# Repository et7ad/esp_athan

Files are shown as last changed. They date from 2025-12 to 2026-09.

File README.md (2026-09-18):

# Athan Clock (ESPHome on an ESP8266)

A small clock that calls the Athan at the exact times of your local mosque. It shows the time and the next prayer on a little screen, plays the Athan through a speaker, and takes its prayer times from tiny JSON files that live in this repository (or any other repository in case you want to replicate the project on your own), one file per day per mosque. This project was built because I could not find one that follows my own mosque's timetable and keeps working when I move.

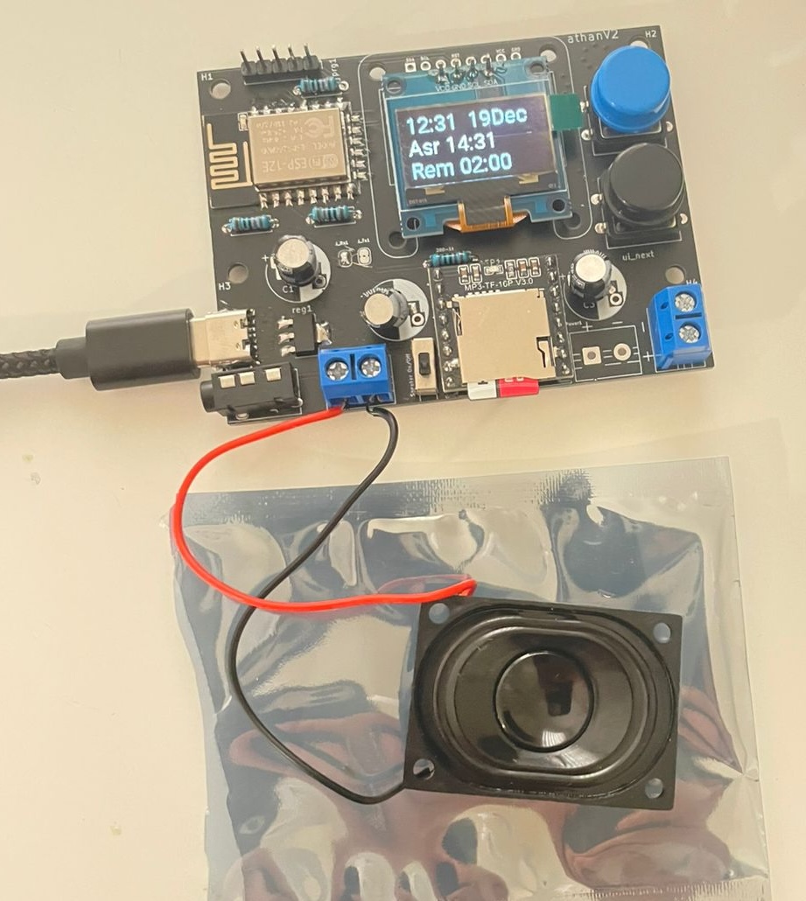
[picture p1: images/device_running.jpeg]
Device running


**Who should read what**

| You are... | Read | Why |
|---|---|---|
| **Someone who already has a device** | **Section 1 only.** | Everything you need to set it up should be in this section. |
| Someone who wants to build one | Section 2 | Parts, wiring, PCB, 3D printed case, preparing the memory card. Needs soldering and a bit of patience. |
| Someone who wants to add a mosque's timetable, or host the data yourself | Section 3 | How the prayer times are stored and served. |
| Someone who wants to change how the firmware behaves | Section 4 and `DEVELOPER.md` | The code is one ESPHome file; the internals are documented there. |

---

## 1. You have the device in your hands

Setting it up is two steps. One, you connect it to your home Wi‑Fi. After that, everything is set from a web page that the clock itself shows on your phone or computer. You can alternatively use the two buttons on the front to do the same things (I think the web page is faster though).

### 1.1 First power‑up: connect it to your Wi‑Fi (once)

1. Plug it in and wait > **2 to 3 minutes**.
2. On your laptop (or phone), open the Wi‑Fi list. A network called **`AthanFallbackHotspot`** appears. Join it with the password **`athan404`**.
3. A page opens by itself asking for your home Wi‑Fi. If it does not, open a browser and go to `192.168.4.1`.
4. Pick your home Wi‑Fi (or enter its SSID manually), type its password, save.
5. The clock restarts, joins your Wi‑Fi, sets its own time from the internet, downloads today's prayer times, and shows the time and the next prayer. From then on it does this by itself every day.

You do this **once**. The clock keeps the Wi‑Fi you gave it, together with all your other settings, in its own memory: unplug it, move it to another socket, leave it off for a month, plug it back in, and it reconnects to the same network by itself. The hotspot only comes back when you want a different network (see below) or when the network it knows is not there.

Two things to know:

- The clock only sees **2.4 GHz** Wi‑Fi networks. Most home routers have one; if yours shows two networks (for example "home" and "home‑5G"), pick the one without "5G".
- If you move it to another home, just plug it in: when it cannot find the Wi‑Fi it knows, it opens the `AthanFallbackHotspot` network by itself after two or three minutes, and you repeat steps 2 to 4. However, if you want to make it **forget** a Wi‑Fi when that network is still in range (for example to move the clock to a different network in the same home): plug it in **while holding both front buttons**, then let go. Within a little while the LED blinks twice, the clock restarts, and the hotspot appears.

### 1.2 Set everything from the web page

On a phone or computer connected to the same Wi‑Fi, open a browser and go to:

**`http://athan.local`**

If that address does not open (it depends on your phone and router, and Android phones usually cannot open `.local` names), use the clock's own IP address instead: on the device use the two buttons, press **Select** (the upper button), then press **Next** (the lower button) until the screen says **Info**, press **Select** again, and the screen shows an address like `192.168.1.42`. Type that into the browser. Your router's app or admin page also lists it, under the name `athan`. (optional): You usually can tell your router to always give the clock the same address (this is often called "DHCP reservation" or "static lease") and bookmark it.

<table><tr>
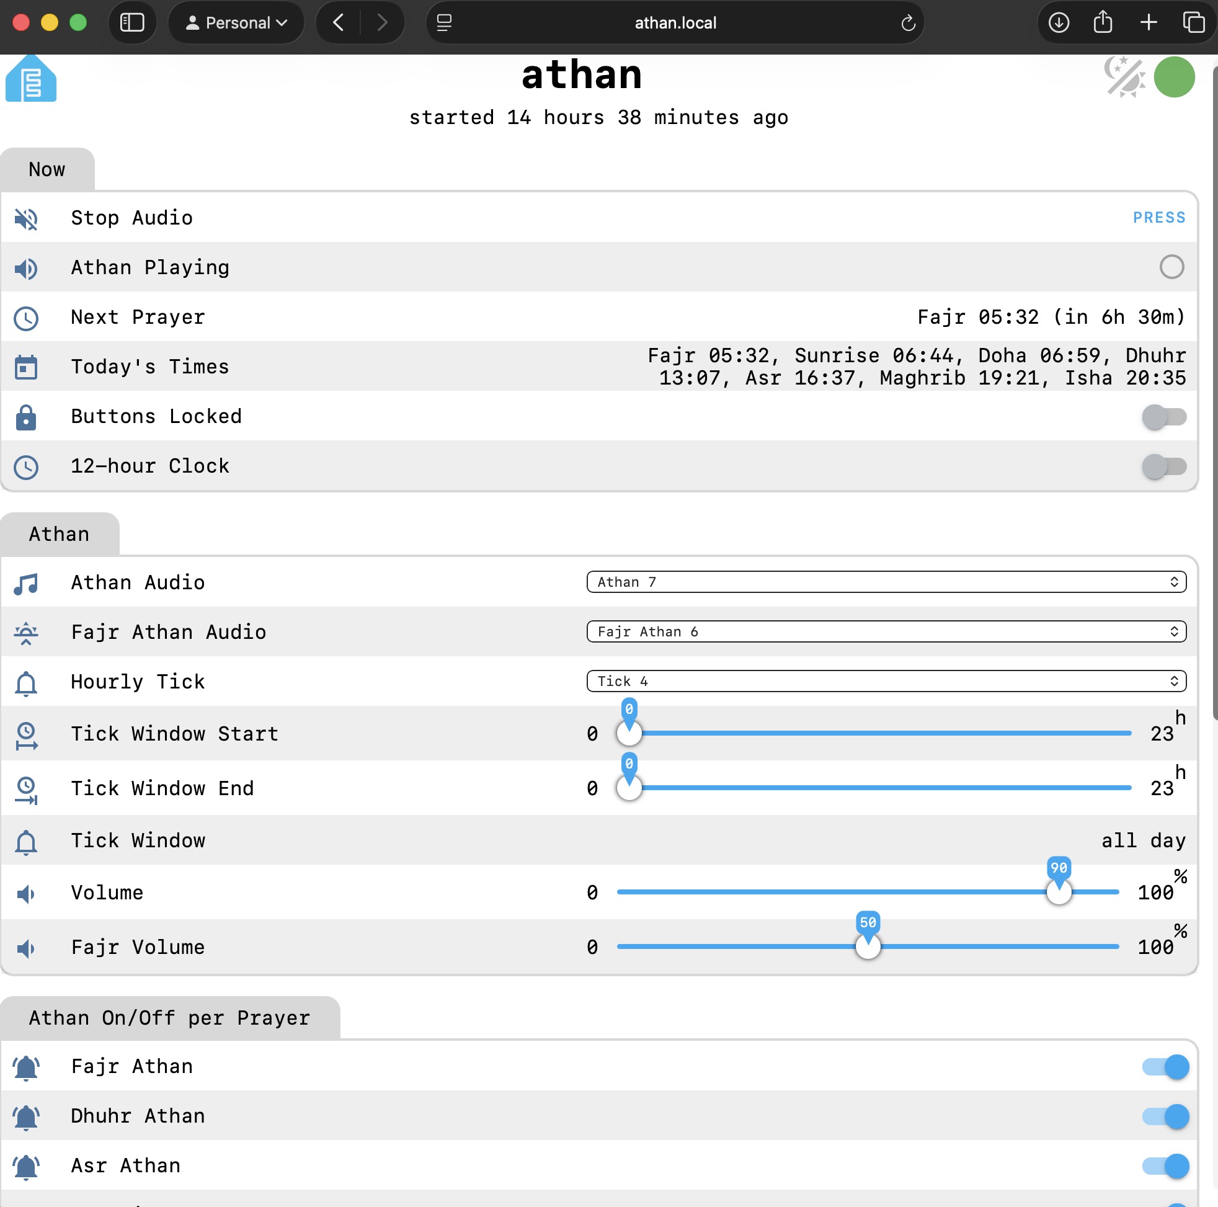
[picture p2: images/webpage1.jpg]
Web page, top half
<td></td>
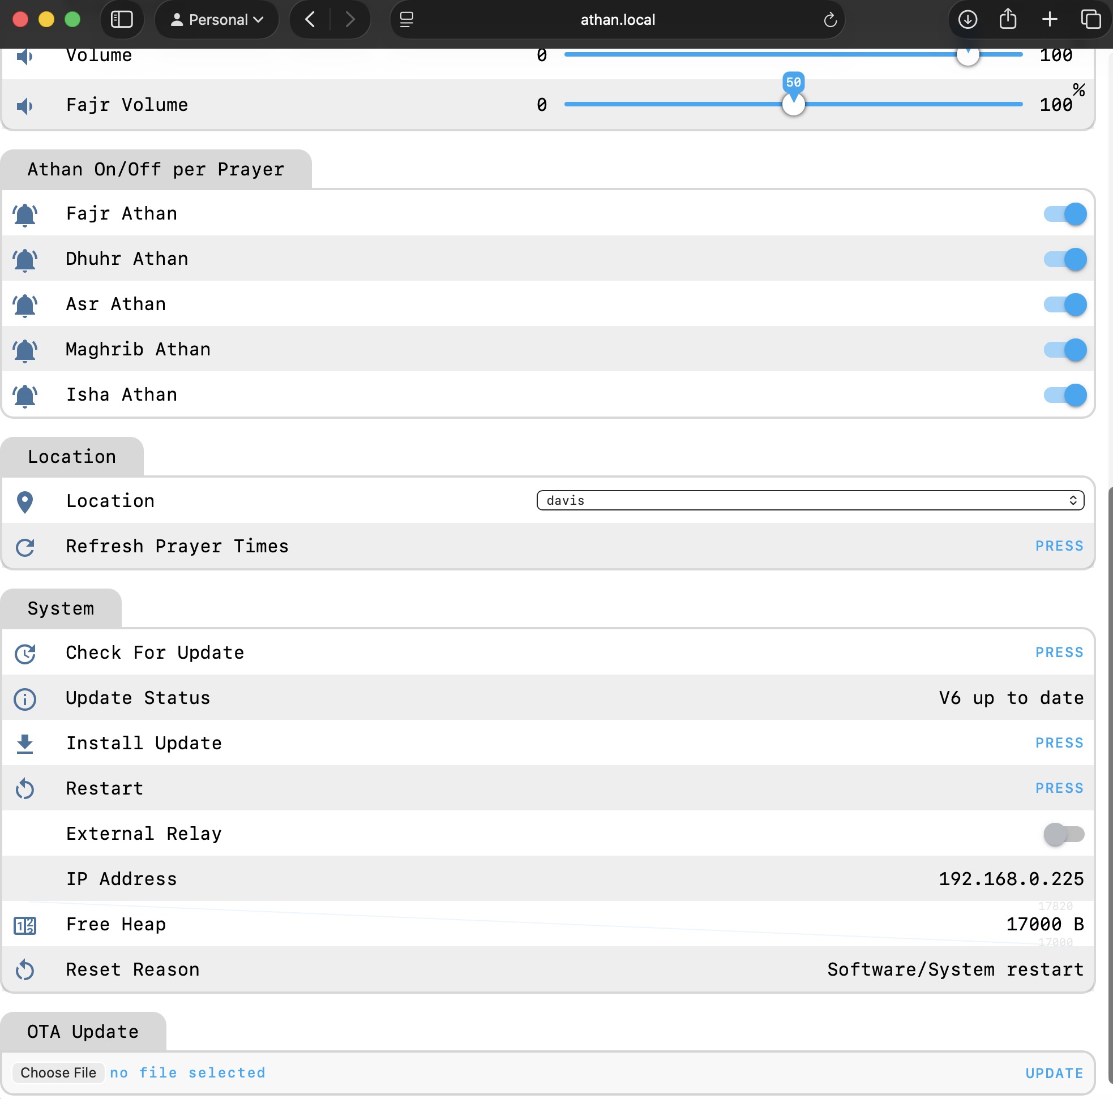
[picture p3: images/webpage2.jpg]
Web page, bottom half
<td></td>
</tr></table>

The page is organised in groups:

- **Location** – your mosque. Pick it from the list and the clock downloads that mosque's timetable and time zone. The list of mosques is in section 3.4; if yours is missing, ask me and I will add it.
- **Athan Audio** – which athan-recording is used for Dhuhr, Asr, Maghrib and Isha. Changing it plays a 20‑second preview.
- **Fajr Athan Audio** – which athan-recording is used for Fajr. Also previews.
- **Volume** and **Fajr Volume** – the Fajr Athan has its own volume, so it can be gentler at dawn (or more loud if you want to count on it to wake you up 😴).
- **Hourly Tick** – an optional short sound at the top of every hour, and **Tick Window Start / End** to allow it only during part of the day. The tick plays at every full hour from Start up to, but not including, End: with Start 7 and End 22 it ticks at 7:00, 8:00 … 21:00 and stays quiet at night. The window can be any stretch of the day, including one that runs through midnight: set Start *higher* than End (for example Start 22, End 7) and it ticks from 22:00 through the night until 6:00. On the page that simply means the upper slider sits higher than the lower one. Start equal to End means all day. You can completely turn the tick off by choosing **None** for the sound.
- **Fajr / Dhuhr / Asr / Maghrib / Isha Athan** – five switches to turn the call off for a particular prayer. The clock still shows and counts down to that prayer; it just stays silent. Visual cue: if the Athan is off, the next prayer name on the screen is partially str~~icken~~-thr~~oug~~
- **12‑hour Clock** – show `5:04 PM` instead of `17:04`.
- **Buttons Locked** – makes the two front buttons do nothing except silence the sound (I guess mainly for kids?). See 1.3 for how to unlock without the page.
- **Stop Audio** – silences whatever is playing right now.
- **Next Prayer**, **Today's Times**, **Athan Playing** – just information.
- **Check For Update / Install Update** – firmware updates, see 1.4.
- **Restart**, **External Relay**, **IP Address**, **Free Heap**, **Reset Reason** – restart the clock; switch the relay output if you connected something to it; the address to type in your browser; and two numbers for degbugging purposes that I may ask you for if something goes wrong.

Anything you change on the page takes effect immediately, and the page always shows what the clock is currently doing, even if it was changed with the buttons.

### 1.3 The screen and the two buttons

The screen normally shows three lines: the time and date, the next prayer and its time, and how long until it. A small padlock in the bottom‑right corner means the buttons are locked. A crossed circle with a **W** means the clock has lost Wi‑Fi (it keeps working; it just cannot download tomorrow's times until Wi‑Fi is back).

The two buttons:

- **Select** (upper) – opens the menu. Inside the menu it confirms. While the Athan is playing it silences it.
- **Next** (lower) – inside the menu it moves to the next item. On the normal screen it silences the Athan if one is playing; otherwise it toggles the relay output.

The menu closes by itself after a minute without presses. Its items, in order:

| Item | What it does |
|---|---|
| Athan | choose the recording for Dhuhr, Asr, Maghrib, Isha (Next previews, Select keeps) |
| Fajr Athan | choose the recording for Fajr (previews at the Fajr volume) |
| Athan On/Off | Next moves through Fajr, Dhuhr, Asr, Maghrib, Isha; Select flips one on or off; Select on **Done** leaves |
| Hourly Tick | choose the hourly sound, or None |
| Tick Window | Next moves between Start, End and Done; Select on Start or End lets Next change the hour; Select again confirms. The third line always shows how long the window is. Start above End means the window runs through midnight |
| Location | your mosque |
| Update | first Select checks for a new firmware, second Select installs it |
| Volume | Next lowers by 10 % (wraps around to 100 %), a tone plays at the new level, Select keeps |
| Fajr Volume | the same, for Fajr |
| Clock | Select flips between 24h and 12h |
| Lock Buttons | Select locks the buttons and returns to the clock |
| Info | firmware version, the clock's IP address and its `athan.local` name |
| Cancel | back to the clock |
| Q | an advanced option that is **off** by default. If it is ever **ON** press select to turns it off |

To **unlock** the buttons without the web page: unplug the clock, then plug it back in while holding **one** of the two buttons (either one). The LED blinks three times quickly and the buttons work again.

### 1.4 Living with it

- **At prayer time** the Athan plays and the LED stays on for a few minutes. Either button, or **Stop Audio** on the page, silences it. Sunrise and Doha are shown but never call.
- **Fajr** uses its own recording and its own volume, the ones you chose under Fajr Athan Audio and Fajr Volume.
- **Firmware updates** need no cable. On the page press **Check For Update**; if a newer version exists, **Install Update**. On the device: menu, **Update**, Select twice. The clock restarts by itself when done.
- **No screen?** The clock works without it: it still calls the Athan and serves the web page. If you plug a screen in later it comes alive within about 10 seconds.
- **Speaker too quiet?** The board has a jack for an external powered speaker (any small PC speaker with its own power). Plug it in and flip the small speaker switch on the board so only the external one is used.

### 1.5 If something is off

- **`athan.local` does not open.** Use the IP address instead (section 1.2). Android in particular never opens `.local` names. Some routers also answer `http://athan/` or `http://athan.lan/`.
- **The buttons do nothing.** Look for the padlock in the corner: the buttons are locked. Switch **Buttons Locked** off on the page, or unplug and replug while holding one button.
- **The sound is wrong: nothing plays, several clips play one after another, the wrong recording, or it keeps playing on its own.** The audio module inside is probably a clone of a common MP3 player and occasionally gets confused, most often right after a button press. The firmware already avoids the usual triggers, but when it happens the fix is simple: **unplug the power and plug it back in.** That is all it needs.
- **The screen is dark or frozen.** Screens clones occasionally lock up; unplug and replug fixes them too. If you unplugged the screen yourself while the clock was running, plugging it back in is handled once; a second time needs a power cycle. The clock keeps calling the Athan meanwhile.
- **The time or the prayer times look wrong.** Check the Wi‑Fi mark on the screen and the **Location** on the page, then press **Refresh Prayer Times**. The clock can only download times when it is online; if it has been offline for more than a day it keeps yesterday's times until it reconnects.
- **You want to see the last restart reason or the memory.** They are the last two rows on the page. If **Reset Reason** ever says `Exception`, tell me; it is not expected.

### 1.6 Home Assistant (optional)

If you run Home Assistant, add the clock through the ESPHome integration; it is discovered automatically. When asked for the key, use:

`jAOYf5QQGoONCqGQnC7fwPhSeb/ZTUTlawp1Lvu63ZI=`

Everything on the web page becomes an entity in Home Assistant: the selects, sliders, switches, buttons and readouts. The **External Relay** switch is handy for things like the IoT power strip below, to switch an amplifier or a light with the Athan.

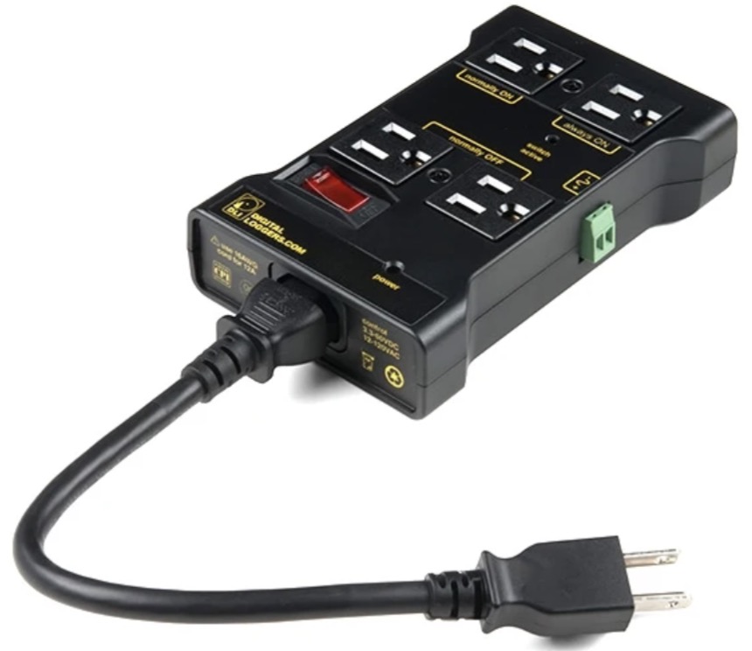
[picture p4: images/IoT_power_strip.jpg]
IoT Power Strip


That is the end of what a device owner needs. The rest of this page is for people building, feeding or changing the clock.

---

## 2. Building your own device

For people who are comfortable with basic electronics and 3D printing and want to assemble a unit from scratch. You will end up with the same device described in section 1.

### 2.1 Parts

- ESP8266 D1 Mini (or an ESP‑12 module, as on the PCB).
- DFPlayer Mini MP3 module with a microSD card.
- SSD1306 128×64 I2C OLED display.
- Two momentary push buttons (Next, Select).
- Optional relay module on `GPIO13`.
- 5 V input, 3.3 V regulator for the ESP8266, a speaker or an external powered speaker on the jack.

The parts list with pictures is in `BOM.md`, which points at the KiCad‑generated BOM files under `hardware/pcb/athan_kicad/BOM/`.

### 2.2 Wiring

`WIRING.md` has the full pin table and decoupling notes. In short:

- OLED on I2C: `GPIO4` (SDA), `GPIO5` (SCL); reset on `GPIO16` (only 7/8‑pin modules have it).
- DFPlayer on the hardware UART: `GPIO1` (TX) and `GPIO3` (RX), powered from 5 V.
- Built‑in LED on `GPIO2`.
- Next on `GPIO14`, Select on `GPIO12`, both with the ESP's internal pull‑ups.
- Relay on `GPIO13`.

A breadboard build works with the same pins.

### 2.3 PCB and enclosure files

- KiCad project (schematic, layout, settings): `hardware/pcb/athan_kicad/`. Renders: `hardware/pcb/athan_kicad/generated_imgs_and_3d/`.
- Enclosure (STL, STEP, Fusion, and a ready gcode): `hardware/encolsure/Iteration13/`. There are top halves for a round or a rectangular speaker and for two display variants; pick the pair that matches your parts.

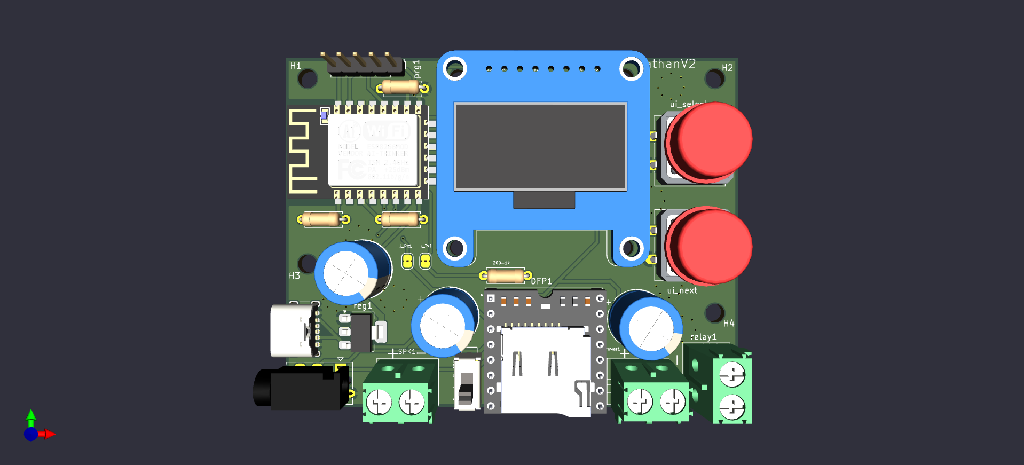
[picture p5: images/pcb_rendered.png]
PCB rendered

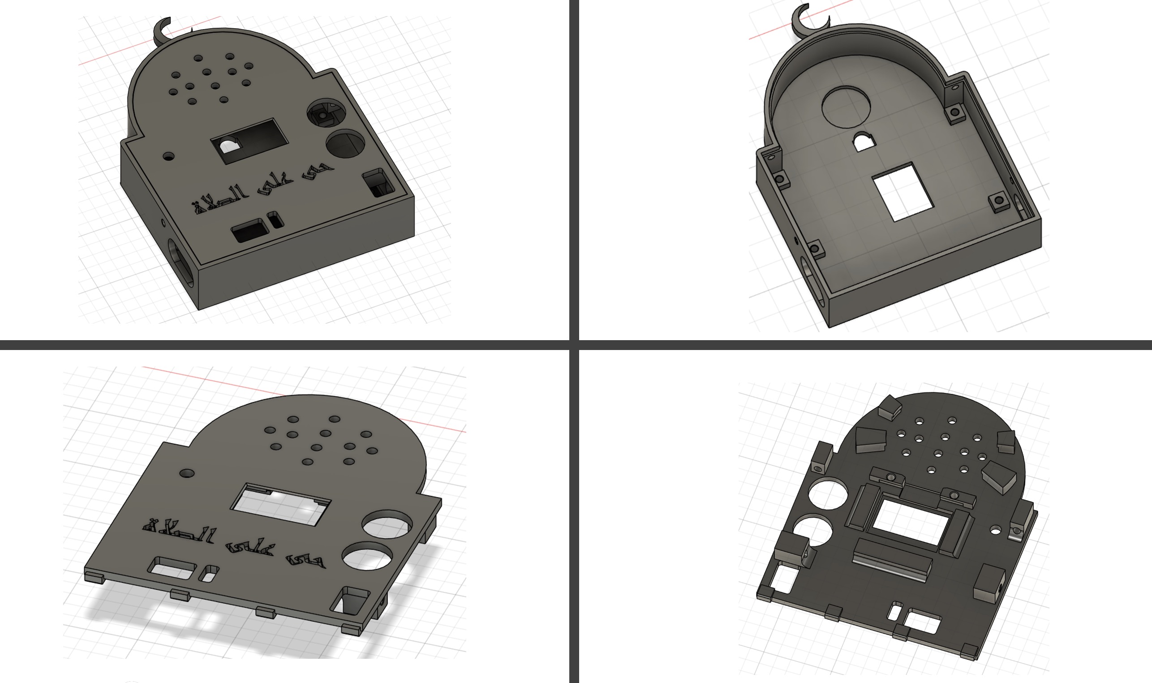
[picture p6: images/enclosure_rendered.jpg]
Enclosure rendered


The PCB accepts several OLED footprints: an 8‑pin header, two 4‑pin I2C footprints with the two common pin orders (`GND‑VCC‑SCL‑SDA` and `VCC‑GND‑SCL‑SDA`; match your module's silkscreen), and a 7‑pin SPI footprint that the firmware does not use.

### 2.4 Flashing the first time

The DFPlayer shares the UART pins that are also used for programming, so the order matters:

1. Solder the ESP module, the power parts and the headers. **Do not solder the DFPlayer yet.**
2. Connect a 3.3 V USB‑to‑serial adapter (CP2102, CH340, FT232...) to the programming pins: `GND` to `GND`, adapter TX to `ESP_RX`, adapter RX to `ESP_TX`, 3.3 V to `ESP_VCC`. Never feed 5 V into `ESP_VCC`.
3. Hold `GPIO0` to `GND` while powering up; that puts the ESP8266 into its serial bootloader.
4. Flash the firmware. Either build it yourself from `firmware/athan.yaml` with ESPHome (you need a `secrets.yaml` next to it with `wifi_ssid` and `wifi_password`), or flash a released `.bin` with `web.esphome.io` in a supported browser, or any ESP8266 flashing tool.
5. Now solder the DFPlayer.

From the second PCB revision on, the DFPlayer's UART lines pass through a small solder jumper, bridged by default. If you ever need the serial header again with the DFPlayer already in place, cut the jumper, flash, and bridge it again with a blob of solder.

### 2.5 Flashing afterwards (no cable)

- From the device: menu, **Update** (checks `docs/firmwareinfo/latest.json` in this repo, then installs).
- From the web page: **Check For Update** and **Install Update**, or the **OTA Update** form at the bottom of the page where you pick a `.bin` file. In Safari on macOS the file picker greys out `.bin` files; use Chrome, or from a terminal:

  ```bash
  curl -F "update=@/path/to/firmware.bin" http://athan.local/update
  ```

- From the ESPHome dashboard or CLI (`esphome run firmware/athan.yaml`).
- If the clock is in its `AthanFallbackHotspot` mode, `http://192.168.4.1` also offers a firmware upload.

If you host your own firmware for the in‑device update, the `.md5` file next to the `.bin` must contain only the checksum string, nothing else.

### 2.6 Preparing the memory card

The DFPlayer does not care about file names; it numbers files by the **order they were copied** to the card. So the card better be written by the script, not by drag and drop.

1. Put the card in the computer (Mac or Linux). Everything on it will be erased, whatever its name or content.
2. Put the audio files in one folder on your computer, named as in the table below.
3. Open `scripts/sd_card_cpy_script.sh` and set `SRC` to that folder. On a Mac also set `DEST` to the mounted card (for example `/Volumes/AUDIO`); on Linux leave `DEST` alone.
4. Run it in a terminal: `bash scripts/sd_card_cpy_script.sh`. On Linux it lists the removable disks, asks which one is the card, and asks for your password once. Answer `YES` when it asks to erase and format the card. It then copies the files, cleans up, reads the card back the way the DFPlayer reads it, and prints the 48 tracks in the order the module will see them.
5. The last lines must say **Card is good** and then **Card ejected**. Do not mount the card on the computer again; put it in the DFPlayer and power the clock. If the script says **PROBLEM** instead, run it again and let it format.

| Files | Names | What they are |
|---|---|---|
| 1–10 | `A1`–`A10` | Athan recordings, regular wording |
| 11–20 | `B1`–`B10` | hourly tick sounds |
| 21–24 | `C1`–`C4` | short tones used by the menu (22 = volume tone, 23 = click) |
| 25–34 | `D1`–`D10` | audio used by the advanced `Q` option |
| 35–44 | `F1`–`F10` | Athan recordings with the Fajr wording (`F<k>` is usually the same reciter as `A<k>`; if a reciter has no Fajr recording, copy `A<k>` again as `F<k>`) |
| 45–48 | `Z_fallback_1`–`4` | a short "please restart" message that plays if the DFPlayer counts files wrongly; must be last |

Cards made for firmware V5 or older lack the `F` files and must be redone for V6. Cards made for V6 before the current script can be missing Fajr athans 7–10 and the fallback message for the DFPlayer (see below) and should be redone with the current script.

Why the script formats and checks: on a Mac, every file written to a card of this kind gets a hidden twin named `._name.mp3`, which the script has to delete again, and every deleted twin leaves two dead slots in the card's table of contents. With 48 files that table needs 165 slots. A card formatted the usual way (Disk Utility's default for cards up to 8 GB) has room for only 128 slots in the first block of that table, and the DFPlayer never reads past the first block: the Mac shows all 48 files, but for the module Fajr athans 7–10 and the fallback message do not exist. So the script formats the card with large blocks (1024 slots), keeps Spotlight and the file‑event logger off the card (two tiny marker files it leaves behind on purpose), and at the end trusts only what it reads back from the card, not what Finder shows. If you ever see `._` files on the card, run the script again and let it format rather than deleting them by hand. Linux makes no twins, but a card keeps every leftover of its earlier life until it is formatted, so the script erases and checks there too.

To look at a card without changing anything, for example one that plays nothing or the wrong thing for some number, run:

```bash
INSPECT=yes bash scripts/sd_card_cpy_script.sh
```

It prints the tracks exactly as the DFPlayer counts them, with a note on every entry that the module cannot reach.

### 2.7 3D printing

PLA is fine indoors; PETG or ABS for a warm spot. 0.2 mm layers, 3 to 4 perimeters, 15 to 25 % infill. Print the top and bottom with their flat faces on the bed. Supports are rarely needed if you set the overhang angle to 80° and the horizontal expansion to about 0.8 mm (maybe inside the big side openings and under the crescent).

Thanks to [Ahmed Nader](https://github.com/iNader) for guidance on component placement and to [Omar Ramadan](https://github.com/omarramadan913) for participating in the enclosure 3D design.

---

## 3. Prayer‑time data

For people who want to add a mosque's timetable, correct one, or host the data themselves. The clock never calculates prayer times; it reads them from small text (JSON) files, so it always matches what your mosque publishes.

### 3.1 Where the data lives

By default the firmware reads the `docs/` folder of this repository, served over plain HTTP through the [raw.githack](https://raw.githack.com) mirror (GitHub itself is HTTPS only, which this small chip does not do):

- Time zone per mosque: `docs/timezones/<key>.json`, containing `{ "TZ": "..." }`.
- Daily times: `docs/athantimes/<key>/<year>/<DDD>.json`, one file per day, `DDD` being the day of the year with three digits (`001.json` is January 1st).
- Firmware pointer: `docs/firmwareinfo/latest.json`.

The URLs the firmware builds are `http://rawcdn.githack.com/et7ad/esp_athan/master/docs/timezones/<key>.json` and `http://rawcdn.githack.com/et7ad/esp_athan/master/docs/athantimes/<key>/<year>/<DDD>.json`.

### 3.2 File format

The exact rules are in [prayertimes_specs.md](prayertimes_specs.md); follow it to the letter, the firmware is a small parser. In short: one JSON object per day, every value a string, times as `HH:MM` with leading zeros. Example:

```json
{
  "year": "2025", "month": "1", "#": "Wednesday", "day": "1",
  "fajr": "06:05", "fajr_iqa": "06:30",
  "sunrise": "07:22", "doha": "07:37",
  "dhuhar": "12:15", "dhuhar_iqa": "12:35",
  "asr": "02:44", "asr_iqa": "03:15",
  "maghrib": "05:04", "maghrib_iqa": "05:09",
  "isha": "06:19", "isha_iqa": "08:00"
}
```

The time‑zone file uses the POSIX form, for example `{ "TZ": "PST8PDT,M3.2.0,M11.1.0" }`. Find yours in the [posix_tz_db](https://github.com/nayarsystems/posix_tz_db/blob/master/zones.csv) list; the `Continent/City` form does not work reliably on this chip.

`scripts/break_json.py` turns a whole‑year source file into the daily files, filling missing iqama fields with an offset and computing Doha as sunrise plus 15 minutes. `scripts/santaclara_prayer_times_parser.py` extracts a year from the MCA PDF timetable. The Davis data comes from Dr. Albara Ramli's site (<https://albara.ramli.net/ar/>).

### 3.3 The list of mosques in the firmware

The mosque keys live in exactly one place in `firmware/athan.yaml`: the `options:` list of the **Location** select. The Location menu, the web page and the URLs all read it. The order is what the clock remembers, so existing entries are never moved or removed; new mosques replace the `masjidN` placeholders.

| Slot | Key | Mosque | Map |
|---|---|---|---|
| 1 | `davis` | Islamic Center of Davis, times from Dr. Albara Ramli's site matching his [Iqamah Times](https://albara.ramli.net/iqamah/) app | https://maps.app.goo.gl/TS9X4CXDYKfkRHph6 |
| 2 | `sclaramca` | Muslim Community Association (MCA), Santa Clara, times from [mcabayarea.org](https://www.mcabayarea.org) | https://maps.app.goo.gl/86ttxawSJ9t7fXnEA |
| 3 | `sclaraalnoor` | Masjid Al‑Noor, Santa Clara, times from [mcabayarea.org](https://www.mcabayarea.org) | https://maps.app.goo.gl/ZAGiTFhHkNFhijHBA |
| 4 | `sacramento` | Sacramento area mosque (to be detailed) | |
| 5 | `cairo` | Cairo profile (to be detailed) | |
| 6 | `woodland` | Woodland Mosque, <https://woodlandmosque.com> | https://maps.app.goo.gl/cv6gB9eWJYny81SWA |
| 7–14 | `masjid7`…`masjid14` | placeholders | |
| 15 | `masjid15` | Visalia, California, times from [IslamicFinder](https://www.islamicfinder.org/) (adhan official; iqama and Doha derived); steps in `docs/athantimes/masjid15/README.md` | |

I intend, God willing, to keep the files for these mosques up to date. If you would like a placeholder slot used for your mosque, open an issue or contact me with the details.

### 3.4 Hosting the data yourself

1. Create a repository (or any HTTP server) with the same layout: `docs/timezones/<key>.json` and `docs/athantimes/<key>/<year>/<DDD>.json`.
2. Generate the daily files (adapt `scripts/break_json.py`).
3. In `firmware/athan.yaml`, change the two base URLs (in the `change_location_handler` and `load_prayer_times` scripts) to your host.
4. Build and flash (section 2.4 or 2.5).

---

## 4. Changing the firmware

For people who want to change how the clock behaves. The whole firmware is one ESPHome file, `firmware/athan.yaml`; there is no other source code. Build and flash with:

```bash
# needs a secrets.yaml next to the yaml with wifi_ssid and wifi_password
esphome run firmware/athan.yaml
```

`DEVELOPER.md` explains the internals: the globals and scripts, how the next prayer is computed, how the downloads are parsed, the menu state machine, the web entities, and the limits of the ESP8266 (memory and the saved‑settings store) that shape several decisions. `todo.md` lists planned hardware changes.

A few things worth knowing without opening that file:

- Every control on the web page is also a plain HTTP call, useful for scripts and phone shortcuts:

  ```bash
  curl -X POST http://athan.local/button/stop_audio/press
  curl -X POST "http://athan.local/number/volume/set?value=40"
  curl -X POST "http://athan.local/select/athan_audio/set?option=Athan%203"
  curl -X POST http://athan.local/switch/fajr_athan/turn_off
  curl -X POST "http://athan.local/select/location/set?option=woodland"
  curl http://athan.local/text_sensor/next_prayer
  ```

  `scripts/relay_control.sh` and `scripts/relay_control_native.py` do this for the relay.
- The device's log can be streamed to the web page by setting `log: true` under `web_server:` in the yaml (off by default to save memory).
- The Home Assistant API can be turned off in the yaml to free memory; the comment above the `api:` block says what you lose.

---

## 5. Why this exists, and similar projects

I wanted the Athan called reliably at the times my own mosque uses, without reprogramming anything when I move or give a clock to a friend. Everything mosque‑specific lives in data files in Git, so the same device follows any timetable. It is ESPHome rather than a hand‑written Arduino sketch, so it plugs into Home Assistant and benefits from ESPHome's updates.

Two projects that do more, differently (Good effort MashaAllah):

- [Muslim Prayer Time (Solat Time) on ESP32](https://fornextlife.wordpress.com/2021/03/07/muslim-prayer-time-on-esp32/) uses an online prayer‑time API, an LCD and a browser configuration page.
- [Islamic Prayer Times on an ESP32 TTGO T‑Display](https://www.instructables.com/Islamic-Prayer-Times-ESP32-TTGO-T-Display/) finds your position through Google APIs and shows a map and the qibla on a colour screen.

Both compute or fetch times from services; this one plays exactly what your mosque publishes.

---

## 6. Getting a unit, contributing, license

If you would like a clock but do not want to build one, reach out through the repository. If I have spare parts I am happy to build one for free; otherwise you can cover the components and I will assemble and flash it, whenever I find the time ;-;

Bugs, ideas, or a mosque to add: open an issue. The project is MIT licensed; fork it, adapt it, extend it as you like.

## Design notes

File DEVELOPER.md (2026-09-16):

## Developer Notes — `athan.yaml` and internals

This file is meant for people who want to change the logic or port the idea to slightly different hardware. It assumes you already read the top‑level `README.md`.

---

### High‑level architecture

- **Platform:** `esp8266` with `board: d1_mini`.
- **ESPHome components used:**
  - `dfplayer` over `uart` for audio playback.
  - `ssd1306_i2c` (128×64) for the UI.
  - `time:` `sntp` for wall‑clock time.
  - `http_request` for JSON and firmware metadata fetching.
  - `api`, `ota`, `wifi`, `captive_portal`.
- **Logic location:** Almost all behaviour lives in inline C++ `lambda`s inside `globals`, `script`, `binary_sensor` handlers, and the `interval` / `time` triggers in `athan.yaml`.

At boot, the firmware restores persisted settings (location, volume, chosen Athan file), applies the saved timezone, and, once SNTP is valid, loads the correct prayer JSON for the current day and location.

---

### Important globals

Some of the key globals in `athan.yaml`:

- `volume_level` (int, persisted) – 0–100% volume, mapped to DFPlayer’s 0–30 range on boot and whenever it changes.
- `athan_file_index` (int, persisted) – regular athan choice `k` = 1–10, file `athan_file_first - 1 + k`.
- `fajr_athan_choice` (int, persisted) – Fajr athan choice 1–10, file `fajr_file_first - 1 + choice`; `-1` until copied from the regular choice on the first boot after the update. `fajr_athan_index` is its submenu cursor.
- `htick_file_index` (int, persisted) – DFPlayer file number to play at the top of each hour (0 = disabled).
- `athan_enabled[7]` (bool array, persisted, all `true`) – per-prayer athan ON/OFF, indexed like `prayer_hours` (0 Fajr, 3 Dhuhr, 4 Asr, 5 Maghrib, 6 Isha; 1 and 2 unused).
- `mute_index` (int) – cursor inside the Athan On/Off submenu (0–4 prayers, 5 = Done).
- `buttons_locked` (bool, persisted) – child lock for the two buttons; checked first in both `on_press` handlers.
- `fajr_volume_level` (int, persisted) – volume for the Fajr athan and the Quyam audio; `-1` until copied from `volume_level` on the first boot after the update.
- `htick_start_hour` / `htick_end_hour` (int, persisted) – hourly-tick window `[start, end)`; equal = all day.
- `clock_12h` (bool, persisted) – 12-hour rendering on the OLED and in the web texts; nothing stored changes.
- `tickwin_index` (int) – cursor inside the Tick Window submenu (0 Start, 1 End, 2 Done).
- `selected_location_index` (int, persisted) – index into the Location select's `options:` list.
- `selected_location_tz` (string, persisted) – POSIX TZ string (for example `PST8PDT,M3.2.0,M11.1.0`).
- `prayer_hours[7]` / `prayer_minutes[7]` (`uint8_t`, persisted) – daily prayer schedule as parsed from JSON; kept in flash so a same-day reboot without Wi-Fi still calls the athan. Bytes, because on the ESP8266 each persisted object costs its size in 4-byte words plus one checksum word (an `int[7]` would cost 8 words, `uint8_t[7]` costs 3; a lone scalar costs 2 whatever its type).
- `prayer_times_day` / `prayer_times_year` – day‑of‑year and year for which the above arrays are valid.
- `next_prayer_index`, `next_prayer_hour`, `next_prayer_minute` – computed by `compute_coming_prayer` at boot and at every prayer; not persisted (nor are `quyam_next_*`).
- `athan_playing` – tracks whether DFPlayer is currently playing the Athan.
- `ui_mode`, `ui_menu_index`, `athan_index`, `htick_index`, `location_index` – all used to drive the small menu system.

Several other globals are used only for internal bookkeeping or features that are intentionally not documented in the user‑facing README.

---

### Main scripts and flows

#### `refresh_prayer_times_if_needed`

- Called after Wi‑Fi connection and periodically.
- Checks if we have ever loaded prayer times (`loaded_prayer_times_once`).
- If not, calls `load_prayer_times`.
- If the stored day/year no longer match `now()`, marks the cache as stale and reloads.
- After loading, calls `compute_next_prayer`, `log_prayers`, and `update_display`.

#### `load_prayer_times`

- Builds a URL of the form:

  `http://rawcdn.githack.com/et7ad/esp_athan/master/docs/athantimes/<location>/<year>/<DDD>.json`

  using `selected_location_index`, `sntp_time.now().year`, and `day_of_year`.
- Fetches JSON via `http_request.get` with a small buffer and a hard maximum size.
- Trims everything before the first `{` and after the last `}` to remove noise.
- Parses into an `ArduinoJson` `JsonDocument`.
- Extracts `fajr`, `sunrise`, `doha`, `dhuhar`, `asr`, `maghrib`, `isha` as strings, strips spaces, and fills `prayer_hours`/`prayer_minutes`.
- Performs small PM adjustments (e.g. if Dhuhr hour `< 9`, add 12; for Asr, Maghrib, Isha ensure hours are in the afternoon).
- Sets `prayer_times_day` / `prayer_times_year` to the current day and year and marks `loaded_prayer_times_once = true`.

#### `compute_next_prayer`

- Uses the current time from `sntp_time` and linearly scans the 7 prayer entries.
- First entry that is still in the future becomes `next_prayer_index` and sets `next_prayer_hour` / `next_prayer_minute`.
- If all 7 are in the past, tomorrow’s Fajr is considered the “next” prayer.
- Some additional internal scheduling is done here to prepare extra behaviour around Fajr.

#### `make_athan`

- Sets `athan_playing = true` and stops any web preview.
- Plays the regular recording (`A<athan_file_index>`) or, when `current_athan_prayer_index == 0`, the separately chosen Fajr recording (`F<fajr_athan_choice>`, file `fajr_file_first - 1 + choice`). The tick sets that index *before* executing the script.
- Turns the built‑in LED on for 5 minutes, then off, and marks `athan_playing = false` again.

#### Shared audio scripts

- `silence_audio` – stops the DFPlayer, the debounced `dfp_play`, and `web_preview`, clears `athan_playing`, refreshes the display. Used by both buttons and the web **Stop Audio** button.
- `apply_volume` – clamps `volume_level` and maps 0–100 % to the DFPlayer's 0–30. Used at boot, by the Volume menu and by the web slider.
- `apply_fajr_volume` – same mapping for `fajr_volume_level`. `make_athan` applies it before a Fajr athan (main volume for every other prayer) and `run_quyam` before the Quyam audio; both restore the main volume when they finish, and `silence_audio` restores it as well (except while the Fajr Volume submenu is open).
- `fajr_volume_feedback` – web slider feedback: tone at the Fajr level, then back to the main volume after 1.5 s.
- `dfp_recover` – DFPlayer reset command, 2.5 s wait, stop, main volume. Not called from anywhere yet; kept for a BUSY-pin watchdog on the next PCB (`todo.md`).

#### DFPlayer clone mitigations

The cheap MH2024K/GD3200B clones read the ESP8266 boot ROM's log (GPIO1 = their RX) as commands, need ~2-3 s after power before they listen, and mis-handle commands that arrive back to back. Firmware side: boot waits 3 s, sends `stop` twice, then the volume; `make_athan` waits 50 ms between the volume command and `play_file`; `dfp_play` debounces rapid requests (20 ms). The observed failure on the owner's hardware is triggered by button presses and only clears with a power cycle, which points at the hardware items in `todo.md` (BUSY pin first).
- `web_preview` – plays `dfp_pending_file` for 20 s and then stops (unless a real athan started meanwhile). Used by the web selects (Athan Audio, Fajr Athan Audio, Hourly Tick); restores the main volume when it ends.
- `sync_web_state` – publishes the selects, the volume number and the text sensors from the globals, only when a value changed. Runs from its own `interval: 1s` entry (not from inside `update_display`), so the publish → API/web callbacks always start from the shallow main-loop stack; the ESP8266 loop stack is only ~4 KB and `update_display` is sometimes reached from deep inside HTTP callbacks. Its format strings use `PSTR`/`snprintf_P` so they live in flash.

#### Per‑second tick (`interval: 1s`)

- Ensures the persisted timezone is applied once when SNTP time becomes valid.
- Skips work until prayer times are successfully loaded.
- Checks whether the current time has passed `next_prayer_hour` / `next_prayer_minute` (with some care around Isha and rollover).
- When that condition is met and the prayer is a main prayer with `athan_enabled[i]` true, sets `current_athan_prayer_index` and triggers `make_athan`. Sunrise, Doha and prayers turned OFF only log; in every case it recomputes the next prayer and updates the display.

#### Display update (`update_display`)

- Helpers defined at the top of the lambda: `time_width`/`draw_time` (24 h `HH:MM`, or 12 h `H:MM` in `font1` followed by a small `AM`/`PM` in `font3`, a 3-glyph 10 px font), `draw_lock` (padlock, bottom right when `buttons_locked`) and `draw_speaker` (Volume submenu). Icons are drawn with primitives because the Roboto font has no emoji. Lines that combine text and a time measure both parts first and shrink the gap so nothing overflows 128 px; in 24 h mode the gaps equal the old two-space / one-space layout, so the screen is pixel-identical to V6.

- Clears the OLED and draws either:
  - The menu views (main menu, Athan selection, hourly tick selection, location preview, volume), or
  - The normal view (current time/date, next prayer, and remaining time).
- Includes some small icons and Wi‑Fi indication logic.
- Also enforces menu timeout (after ~60 seconds of inactivity it resets `ui_mode` to 0 and stops any preview audio).

---

### Menu and button handling

- Two GPIO buttons are defined as binary sensors with `INPUT_PULLUP` and `inverted: true`.
- Their `on_press` handlers are implemented in C++ to keep the state machine compact.

Rough behaviour:

- **Normal mode** (`ui_mode == 0`):
  - Select: if Athan is playing, stops it; otherwise enters main menu and plays a small click sound.
  - Next: acts like a “silence” button if Athan is playing, otherwise a no‑op except for a display refresh.

- **Main menu mode** (`ui_mode == 1`):
  - Next: advances `ui_menu_index` (0–13: Athan, Fajr Athan, Athan On/Off, Hourly Tick, Tick Window, Location, Update, Volume, Fajr Volume, Clock, Lock Buttons, Info, Cancel, Q) and updates the OLED. Menu indices are not persisted, so the order can change between versions.
  - Select: dispatches based on the current index to enter the relevant submenu or perform actions such as starting an update check.

- **Submenus** (`ui_mode`):

  | `ui_mode` | Screen | Next | Select |
  |---|---|---|---|
  | 2 | Athan audio | next recording (preview) | store `athan_file_index`, exit |
  | 8 | Fajr Athan | next F recording (preview at the Fajr volume) | store `fajr_athan_choice`, restore main volume, exit |
  | 3 | Hourly tick | next tick (preview) | store `htick_file_index`, exit |
  | 4 | Location | next key (preview) | fetch TZ, store, exit |
  | 5 | Volume | −10 % (wraps) | exit |
  | 6 | Athan On/Off | next of Fajr, Dhuhr, Asr, Maghrib, Isha, Done | toggle `athan_enabled[...]` and stay; on Done exit |
  | 7 | Info (version, IP, `athan.local`) | nothing | exit |
  | 9 | Fajr Volume | −10 % (wraps), tone at that level | restore main volume, exit |
  | 10 | Tick Window list (Start / End / Done; line 3 shows `Window: Nh`) | next entry | Start → 11, End → 12, Done → exit |
  | 11 / 12 | editing start / end hour (`Start>` / `End>`) | hour + 1 (wraps at 24) | back to 10 |

  Main-menu items that act in place: **Clock** (toggles `clock_12h`) and **Q**; **Lock Buttons** sets `buttons_locked` and exits. While `buttons_locked` is set, both handlers return after `silence_audio`; `on_boot` clears the flag when exactly one button is held at power-up (both held stays the Wi-Fi reset).

  Helper indices (`athan_index`, `htick_index`, `location_index`, `mute_index`) do not touch persisted values until the user presses Select.

This design tries to keep actual writes to persisted globals limited to clear confirmation points so accidental button presses are less likely to store half‑finished state.

---

### JSON layout and adding locations

See the main README for the user‑facing explanation. From the firmware side:

- The location keys live in exactly one place: the `options:` list of the `web_location_select` select in `athan.yaml`. `load_prayer_times`, `change_location_handler`, the Location menu and the web page all read it through `id(web_location_select).at(i)`.
- `selected_location_index` is the persisted index; `location_index` is used as a “preview” index while the location submenu is open (and is what the web select writes before calling `change_location_handler`).

Typical steps to add a new mosque:

1. Create `docs/timezones/<newkey>.json` with a `TZ` string.
2. Generate `/<newkey>/<year>/<DDD>.json` for every day of the year.
3. Replace one of the `masjidN` placeholders in the `web_location_select` `options:` with `<newkey>`. Never insert or reorder: the index is persisted on every deployed device.
4. Update the README mosque table (section 3.3), rebuild and flash.

If you prefer not to fork this repo, you can instead mirror the same JSON layout in your own repo and point the URLs to it, as described in the README.

---

### DFPlayer mapping and SD‑card

The DFPlayer is configured via:

```yaml
uart:
  tx_pin: GPIO1
  rx_pin: GPIO3
  baud_rate: 9600

dfplayer:
  id: dfp
```

All file numbers come from the `substitutions:` block at the top of the YAML, so the layout is changed in one place:

| Substitution | Value | Meaning |
|---|---|---|
| `athan_file_first` | 1 | A1–A10 → files 1–10, regular athans; choice `k` → file `athan_file_first - 1 + k` |
| `htick_file_first` | 11 | B1–B10 → files 11–20, hourly ticks; tick `t` → file `htick_file_first - 1 + t` |
| `tone_volume_file` | 22 | volume feedback tone |
| `tone_click_file` | 23 | menu click |
| `quyam_file_first` / `quyam_file_last` | 25 / 34 | D1–D10, picked at random by `run_quyam` |
| `fajr_file_first` | 35 | F1–F10 → files 35–44, Fajr-wording athans; choice `k` → file `fajr_file_first - 1 + k` |

`Z_fallback_1..4` land on 45–48. They are never referenced by number and must be copied last, because the DFPlayer glitch that they cover ends up playing the last file on the card.

The DFPlayer itself ignores file names; it numbers audio files by walking the card's root directory slot by slot (32 bytes per entry) in physical order. See the README’s SD‑card section for user‑facing instructions.

**The root directory must fit in its first block (the "Fajr 7 and 8 don't work" bug, 2026‑09‑15).** On macOS every file created on a FAT volume gets an AppleDouble twin `._name` carrying `com.apple.provenance`; `cp -X`, `cat >`, `touch` and `mkdir` all trigger it (verified on macOS 26), and deleting the twin leaves its two slots dead. Each audio file therefore costs three slots: 48 files plus the two marker files = 165 slots. A FAT32 card with 4 KB clusters (Disk Utility's and Windows' default up to 8 GB) has 128 slots in the first root‑directory cluster, and the cheap modules do not follow the directory into its second cluster, so tracks 41–48 (F7–F10 and `Z_fallback`) are unreachable although Finder lists them. V5 with 38 files used 123 slots and stayed just under the limit. `scripts/sd_card_cpy_script.sh` now (1) formats the card itself: FAT16 up to 2 GB (fixed 512‑slot root directory), FAT32 with 32 KB clusters above (1024 slots per cluster); (2) copies, cleans, unmounts; (3) parses the raw FAT root directory from `/dev/rdiskNsM` with an embedded python3 snippet and prints every audio entry with its slot number in the module's order, failing on any entry beyond the first block, any `._` twin counted as a track, any order mismatch, or a folder with an audio name. `INSPECT=yes` runs only step 3 on an existing card, read‑only. Raw devices need 4 KB‑aligned reads; on macOS the console user can read and `newfs_msdos` removable devices without sudo (the script falls back to sudo). On Linux `DEST` is ignored: the script lists removable disks (`lsblk`, RM=1 or usb/mmc transport, never the disk behind `/`), asks which one is the card (or takes `DISK=/dev/sdX`), confirms, unmounts, `wipefs -a`, writes a one‑partition MBR with `sfdisk` (type `c` for FAT32, `6` for FAT16), `mkfs.fat -F 32 -s 64` (or `-F 16`), mounts it itself under a temp dir with `uid=`, copies, unmounts and runs the same check with `sudo` (block devices are root‑only), then `eject`. The Linux branch was written on a Mac and unit‑tested only with stubbed `lsblk`/`findmnt`; the first real run should be on a spare card. Simulating with disk images (`hdiutil create -fs "MS-DOS FAT32"`, run the script against `/Volumes/NAME`, dump the partition with `dd`, parse) reproduces a real card's layout exactly and is how to test changes without a card.

---

### Display is optional (hot-plug watchdog)

`I2CSSD1306::setup()` probes the I2C address before allocating the frame buffer; no answer → `mark_failed()` and ESPHome carries on without it. `update_display` starts with `if (!id(oled).is_ready()) return;` so nothing draws into a buffer that does not exist (this was a null write and a boot loop in V5 when the display was absent). A 10 s `interval` sends a zero-length I2C write as an ACK probe. A failed display that answers gets `reset_to_construction_state()` + `call()` (ESPHome's full setup: its own probe runs before the buffer is allocated, so a miss just retries next tick and nothing leaks). A display that was working, vanished and came back gets `setup()` again once it has answered two consecutive probes (20 s), because re-sending the same init bytes by hand did not revive the 4-pin modules on real hardware while `setup()` does (the difference was never pinned down). Every such `setup()` allocates a new 1 KB frame buffer and ESPHome never frees the old one (`buffer_` is protected, no accessor), so the watchdog allows exactly one such in-place `setup()` per boot; later replugs only log a warning. The device must never restart itself because of the display (the athan has to keep working on the speaker), so the user power-cycles it when they want the screen back. Orientation and contrast are the `oled_flip_x` / `oled_flip_y` / `oled_contrast` substitutions.

### Web page and Home Assistant entities

`web_server:` runs version 3 with `log: false` (set it to `true` to stream the log to the page) and five sorting groups; every entity carries a `web_server: {sorting_group_id, sorting_weight}` block. Accepted downside: the version 3 OTA upload input carries `accept="application/octet-stream"`, which greys out `.bin` files in Safari on macOS (version 2's form has no filter but shows a flat alphabetical list; the owner chose the grouped layout). Upload from Chrome or `curl -F "update=@firmware.bin" http://athan.local/update`. The firmware is deliberately a single yaml file, so no custom page script is shipped. Every entity is a plain ESPHome template entity that reuses the scripts above:

- `button`: `web_stop` → `silence_audio`; `web_refresh_times`; `web_check_update` / `web_install_update` (same state machine as the Update menu item, `update_check_state` 3 → 1/2 → 4); `web_restart`.
- `select`: `web_athan_select` (Athan 1–10), `web_fajr_athan_select` (Fajr Athan 1–10, previews at the Fajr volume), `web_htick_select` (None, Tick 1–10), `web_location_select` (the 15 keys). Their `set_action` writes the same globals the menu writes, then `publish_state`. They have no `lambda`; `sync_web_state` pushes device-side changes.
- `number`: `web_volume` (0–100, step 10) → `apply_volume`; `web_fajr_volume` (0–100, step 10) → `fajr_volume_feedback`; `web_htick_start` / `web_htick_end` (0–23) write the tick window hours.
- `switch` (`restore_mode: DISABLED`): `web_buttons_locked`, `web_clock_12h` mirror their globals via `lambda`.
- `switch`: `web_athan_fajr/dhuhr/asr/maghrib/isha` use a `lambda` on the global (evaluated every loop, published on change) plus turn on/off actions, and **`restore_mode: DISABLED`**. That last line is load-bearing: with the default restore mode ESPHome calls `turn_off()` inside the switch `setup()` (priority 798), which runs the action before the display (priority 400) has a buffer. The first V6 build crashed on every boot for exactly this reason and also would have muted every prayer at each boot. The `Q` flag is deliberately not exposed as an entity; it stays device-only behind the 10-press guard.
- `binary_sensor`: `web_athan_playing`. `text_sensor`: `web_next_prayer`, `web_today_times`, `web_htick_window` (`all day` or `7:00 AM to 10:00 PM (15 h)`), `web_update_status` (carries the version), `web_ip` (`wifi_info`), `web_reset_reason` (`debug`). `sensor`: `web_free_heap` (`debug`).

**Memory budget (ESP8266, 80 KB RAM).** The linker's `RAM:` line at the end of a build is static usage; V6 sits around 40 KB and everything else (Wi‑Fi stack ~10 KB, entities, API connection, web clients, HTTP fetch buffers, 1 KB display buffer) comes out of the remainder as heap. Two things are easy to get wrong: (1) font glyph tables live in DRAM (`.rodata`), ~32 bytes per glyph, so every font lists its `glyphs:` explicitly instead of the ~100-glyph default; (2) string literals in lambdas are DRAM too, so long format strings use `PSTR()` with `snprintf_P`. Watch **Free Heap** on the web page after any change; a value that keeps dropping toward 8 KB precedes crash-reboot loops.

REST endpoints follow ESPHome's scheme, for example `POST /button/stop_audio/press`, `POST /select/location/set?option=woodland`, `POST /number/volume/set?value=40`; see README section 4.

### Development and testing

Suggested loop when changing the YAML:

1. Install ESPHome and create a `secrets.yaml` with `wifi_ssid` and `wifi_password` that match your local network.
2. Run:

   ```bash
   esphome run athan.yaml
   ```

   This builds and flashes over USB (or OTA once configured).
3. Keep the ESPHome logs open to watch `ESP_LOGI` output from the various components.

If you break parsing or networking code, most errors will show up in the logs (`prayer`, `tz`, `update` tags etc.).

---

### Extending or porting

Some ideas if you want to go further:

- Port to **ESP32** or newer boards and enable HTTPS for JSON endpoints.
- Use a larger screen (TFT) by replacing the `display:` component and rewriting `update_display`.
- Add more menu items or sensors in ESPHome (for example, brightness sensors to auto‑dim the display).
- Replace the JSON host with a small server that generates JSON on the fly from an existing timetable system.

If you do build something on top of this, I would be happy to learn from it.

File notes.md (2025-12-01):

## Project notes

This file collects a few practical notes that do not quite belong in the main README but are still useful when assembling or debugging the device.

The MCU is an ESP8266, powered from 3.3 V via a regulator, and most audio‑related parts prefer a clean 5 V rail.

---

## DFPlayer / MP3 module

Connectivity (as used by `athan.yaml`):

| Module pin / signal | Connected to (MC / peripheral) | Direction | Notes |
|---|---|---:|---|
| TX (module) | MCU RX (`GPIO3`) |  Out → In | Serial TX from module to MCU RX |
| RX (module) | MCU TX (`GPIO1`) |  In ← Out | Serial RX to module from MCU TX |
| VCC / VIN | 5 V (external) | Power | Prefer external 5 V supply, not the 3.3 V regulator |
| GND | GND | Power | Common ground for module, MCU and supply |

Audio outputs (to amplifier or speaker module) are not fixed in this repo and depend on your chosen hardware, but in general you route the DFPlayer’s audio outputs to your amplifier, then from the amplifier to the speaker.

### Preparing the microSD card (important)

The DFPlayer uses simple numeric file indices. For this project the exact mapping is described in the main `README.md`, but all mappings depend on how the card is prepared.

1. **Format the card as FAT (FAT16/FAT32).**  
	On macOS you can do this with Disk Utility.
2. **Do not create folders.**  
	Put all audio files in the root of the card.
3. **Copy files in the desired order.**  
	The first file you copy becomes file `1`, the second becomes file `2`, and so on.
4. **Remove hidden macOS files.**  
	macOS tends to create `.DS_Store`, `.Trashes` and `._*` files. After copying audio files, open a terminal and run (replace `AUDIO` with your card’s name):

	```bash
	cd /Volumes/AUDIO/
	rm -rf .DS_Store .Trashes ._*
	```

5. Safely eject the card, insert it into the DFPlayer, and reboot the device.

This process ensures that DFPlayer numbering matches what the firmware expects.

---

## Power / supply

Quick reminder of the main rails:

| Rail / pin | Connected to | Voltage | Notes |
|---|---|---:|---|
| 5 V (Vin) | DFPlayer VCC, relay VCC | 5 V | Prefer a stable external rail |
| 3.3 V (MCU)  | ESP8266 Vcc, OLED Vcc | 3.3 V | From regulator |
| GND | Common ground | 0 V | Tie all grounds together |

See `WIRING.md` for the full wiring and decoupling suggestions.

---

## Misc notes / ideas

- If audio is noisy, check the 5 V rail and the ground layout and add extra bulk capacitance near the DFPlayer.
- If JSON downloads seem flaky, watch the ESPHome logs for the `prayer`, `tz`, or `update` tags while reproducing the problem.

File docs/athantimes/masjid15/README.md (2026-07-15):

# masjid15 — Visalia, California

This slot's prayer-time data (`docs/athantimes/masjid15/<year>/DDD.json`) is for
**Visalia, California, USA** (Pacific time — see `docs/timezones/masjid15.json`).

`masjid15` is firmware **slot 15**. It was one of the reserved placeholder slots;
the **key is intentionally left as `masjid15`** so the persisted
`selected_location_index` on already-deployed devices keeps pointing at the same
slot. Only the *data* behind the key changed — not its position.

## Where the data comes from

Times are generated from **[IslamicFinder](https://www.islamicfinder.org/)**'s
yearly prayer-times page for Visalia, CA.

1. **Capture the HTML.** IslamicFinder renders the whole year as one HTML page.
   The exact steps to grab that HTML from the browser are shown in the annotated
   screenshot:

   `scripts/helping/parse_islamicfinder_yearly_get_html.jpg`

   Save the captured page as e.g. `Visalia<YYYY>.html` into
   `scripts/helping/preparing/`.

2. **Parse it into per-day JSON.** Run the parser:

   ```bash
   python3 scripts/helping/parse_islamicfinder_yearly.py
   # or point it at a specific file:
   python3 scripts/helping/parse_islamicfinder_yearly.py path/to/Visalia2026.html
   ```

   It writes `001.json … 365.json` (spec: `prayertimes_specs.md`) into a folder
   named after the year, right next to the HTML. Copy that folder here as
   `docs/athantimes/masjid15/<year>/`.

## Important caveat about iqama times

The IslamicFinder source provides **only adhan (call-to-prayer) times plus
sunrise** — it has **no iqama times and no doha**. The parser therefore
**derives** those fields:

- `doha`        = `sunrise` + 15 min
- `fajr_iqa`    = `fajr`    + 30 min
- `dhuhar_iqa`  = `dhuhar`  + 10 min
- `asr_iqa`     = `asr`     + 10 min
- `maghrib_iqa` = `maghrib` + 10 min
- `isha_iqa`    = `isha`    + 20 min

So the `*_iqa` values here are **estimates, not a specific mosque's official
congregation times**. Adjust the offsets at the top of the parser if a real
local schedule is available.

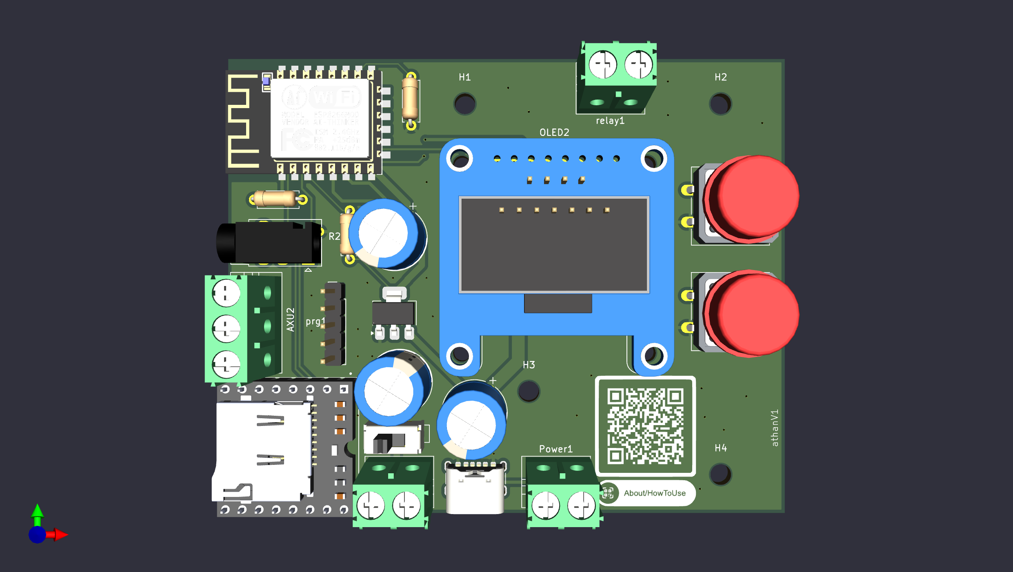
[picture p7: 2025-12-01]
hardware/pcb/athan_kicad/generated_imgs_and_3d/athanV1.png

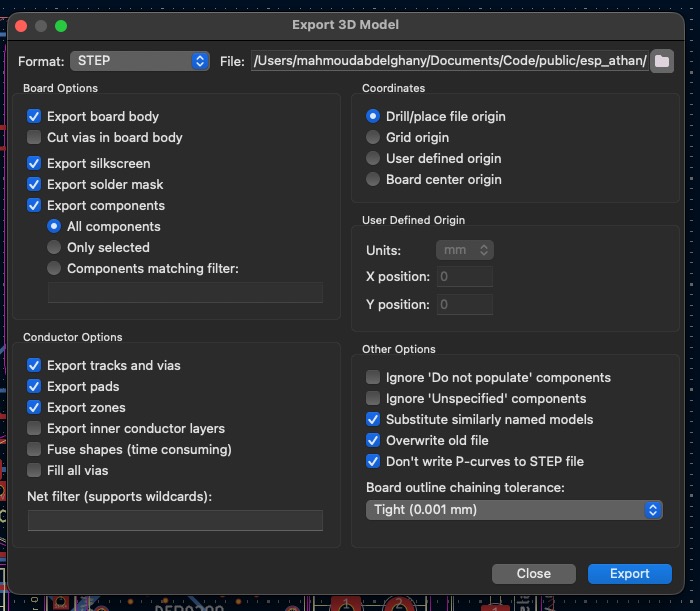
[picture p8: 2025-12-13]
hardware/pcb/athan_kicad/production_files_screenshots/3D_exp.jpg

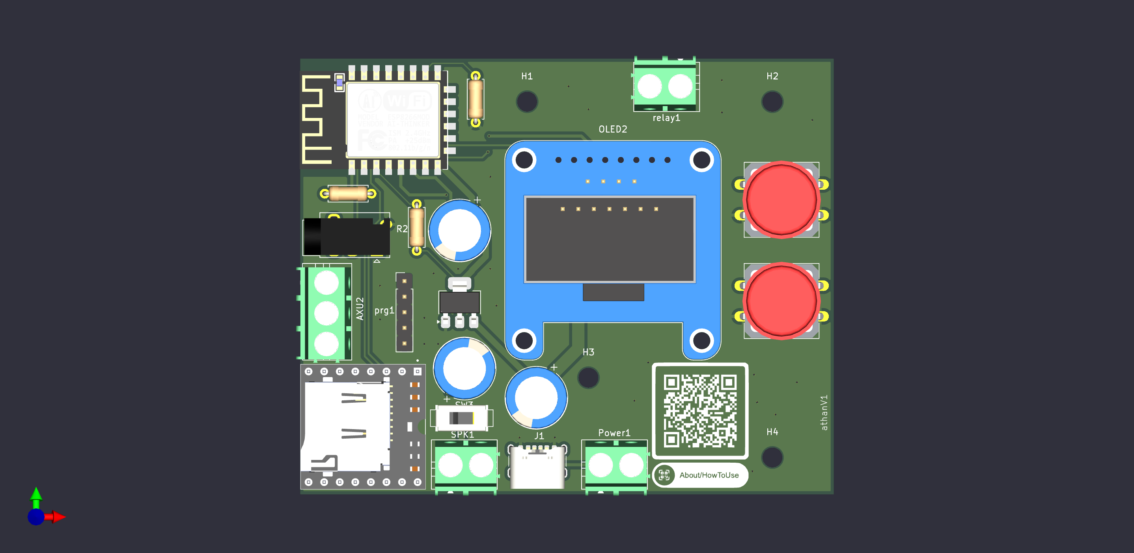
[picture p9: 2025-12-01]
hardware/pcb/athan_kicad/generated_imgs_and_3d/athanV1_img2.png

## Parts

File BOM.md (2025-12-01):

**Bill Of Materials**

The full, PCB‑level Bill Of Materials for this project is exported directly from the KiCad hardware project and lives next to the PCB files:

- CSV: `hardware/pcb/athanV1_PCB/BOM.csv`
- Excel: `hardware/pcb/athanV1_PCB/BOM.xlsx`

Those two files are generated from the schematic/layout in `hardware/pcb/athanV1_PCB/athanV1.kicad_sch` / `hardware/pcb/athanV1_PCB/athanV1.kicad_pcb` and are the **authoritative source** for part numbers, quantities, and footprints when ordering or assembling the board.

If you are sending the board to a PCB assembly house, use the CSV as the reference BOM. If you prefer to browse or tweak the list manually (e.g. to swap vendors or part numbers), open the Excel file.

For enclosure, wiring and general hardware notes, see:

- `README.md` section “Building your own device (hardware and assembly)”
- `WIRING.md` for pinout and wiring details.

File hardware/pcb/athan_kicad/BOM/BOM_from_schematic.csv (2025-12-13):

Reference | Qty | Value | DNP | Exclude from BOM | Exclude from Board | Footprint | Datasheet
C1,C2,C3 | 3 | 100u |  |  |  | Capacitor_THT:CP_Radial_D10.0mm_P5.00mm_P7.50mm | ~
DFP1 | 1 | DFR0299 |  |  |  | project_devs:MODULE_DFR0299
ESP1 | 1 | ESP-12E |  |  |  | project_devs:ESP-12E_SMD | http://l0l.org.uk/2014/12/esp8266-modules-hardware-guide-gotta-catch-em-all/
H1,H2,H3,H4 | 4 | MountingHole |  | Excluded from BOM |  | MountingHole:MountingHole_3.2mm_M3 | ~
J1 | 1 | USB_C_Receptacle_PowerOnly_6P |  |  |  | Connector_USB:USB_C_Receptacle_GCT_USB4125-xx-x_6P_TopMnt_Horizontal | https://www.usb.org/sites/default/files/documents/usb_type-c.zip
J2 | 1 | AudioJack4 |  |  |  | Connector_Audio:Jack_3.5mm_PJ320A_Horizontal | ~
J_Rx1,J_Tx1 | 2 | SolderJumper_2_Bridged |  | Excluded from BOM |  | Jumper:SolderJumper-2_P1.3mm_Bridged2Bar_RoundedPad1.0x1.5mm | ~
OLED1 | 1 | SSD1306_I2C |  |  |  | Display:Adafruit_SSD1306_multi | ~
Power1 | 1 | 5V pow supply |  |  |  | TerminalBlock:TerminalBlock_MaiXu_MX126-5.0-02P_1x02_P5.00mm | ~
prg1 | 1 | Conn_01x05 |  |  |  | Connector_PinHeader_2.54mm:PinHeader_1x05_P2.54mm_Vertical | ~
R1,R2,R3 | 3 | 10k |  |  |  | Resistor_THT:R_Axial_DIN0207_L6.3mm_D2.5mm_P7.62mm_Horizontal | ~
R4 | 1 | 1k |  |  |  | Resistor_THT:R_Axial_DIN0207_L6.3mm_D2.5mm_P7.62mm_Horizontal | ~
reg1 | 1 | AMS1117-3.3 |  |  |  | Package_TO_SOT_SMD:SOT-223-3_TabPin2 | http://www.advanced-monolithic.com/pdf/ds1117.pdf
relay1 | 1 | Relay control |  |  |  | TerminalBlock:TerminalBlock_MaiXu_MX126-5.0-02P_1x02_P5.00mm | ~
SPK1 | 1 | Speaker |  |  |  | TerminalBlock:TerminalBlock_MaiXu_MX126-5.0-02P_1x02_P5.00mm | ~
SW1 | 1 | ui_select |  |  |  | Button_Switch_THT:SW_SPST_Omron_B3F-40xx | ~
SW2 | 1 | ui_next |  |  |  | Button_Switch_THT:SW_SPST_Omron_B3F-40xx | ~
SW3 | 1 | SW_SPST |  |  |  | Button_Switch_THT:SW_Slide-03_Wuerth-WS-SLTV_10x2.5x6.4_P2.54mm | ~

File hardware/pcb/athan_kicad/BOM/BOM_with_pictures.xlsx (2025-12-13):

Reference | Total Qty | Value | Footprint | Link | Pic
C1,C2,C3 | 50 | 100u | Capacitor_THT:CP_Radial_D10.0mm_P5.00mm_P7.50mm |  | #VALUE!
DFP1 | 10 | DFR0299 | project_devs:MODULE_DFR0299 |  | #VALUE!
ESP1 | 10 | ESP-12E | RF_Module:ESP-12E |  | #VALUE!
J1 | 10 | USB_C_Receptacle_PowerOnly_6P | Connector_USB:USB_C_Receptacle_GCT_USB4125-xx-x_6P_TopMnt_Horizontal |  | #VALUE!
J2 | 10 | AudioJack4 | Connector_Audio:Jack_3.5mm_PJ320A_Horizontal |  | #VALUE!
OLED2 | 8 | SSD1306_I2C | 4 PINS - I2C |  | #VALUE!
R1,R2,R3 |  | 10k | Resistor_THT:R_Axial_DIN0207_L6.3mm_D2.5mm_P7.62mm_Horizontal |  | #VALUE!
R4 |  | 1k |  |  | #VALUE!
reg1 | 10 | AMS1117-3.3 | Package_TO_SOT_SMD:SOT-223-3_TabPin2 |  | #VALUE!
SPK1 | 10 | Speaker |  |  | #VALUE!
SW3 | 10 | slide switch 2.54P, 5 or 4 mm is fine | Button_Switch_THT:SW_Slide-03_Wuerth-WS-SLTV_10x2.5x6.4_P2.54mm |  | #VALUE!
T1, T2, T3 | 50 | Terminal block 2 pins | TerminalBlock:TerminalBlock_MaiXu_MX126-5.0-02P_1x02_P5.00mm |  | #VALUE!

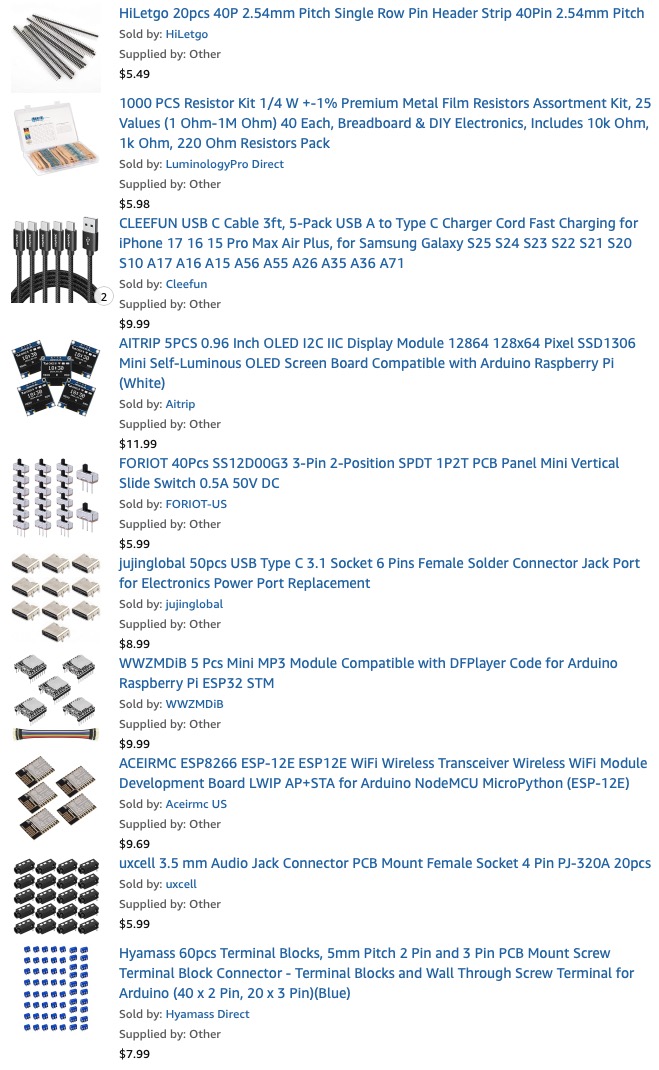
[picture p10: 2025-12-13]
hardware/pcb/athan_kicad/BOM/BOM_in_card_no_speaker_no_buttons.jpg

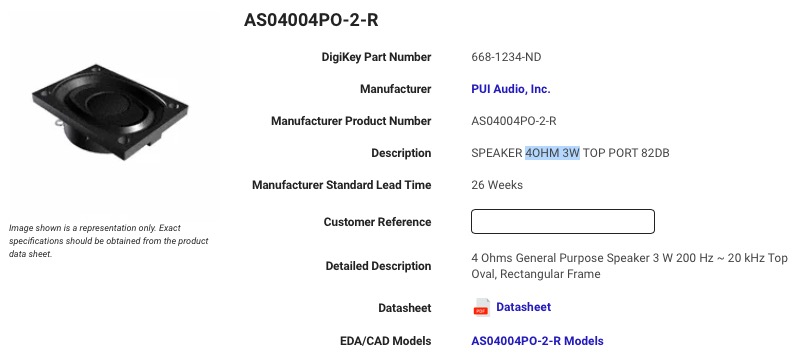
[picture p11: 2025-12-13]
hardware/pcb/athan_kicad/BOM/BOM_in_card_speakers_any_4OHM_3W.jpg

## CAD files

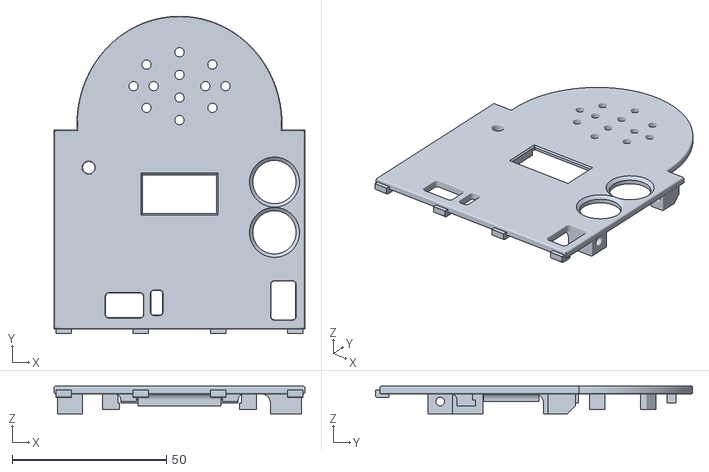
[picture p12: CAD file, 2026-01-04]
hardware/encolsure/Iteration13/top13_RectSpeaker_VDisplay.stl
81.3 x 102.8 x 8.99

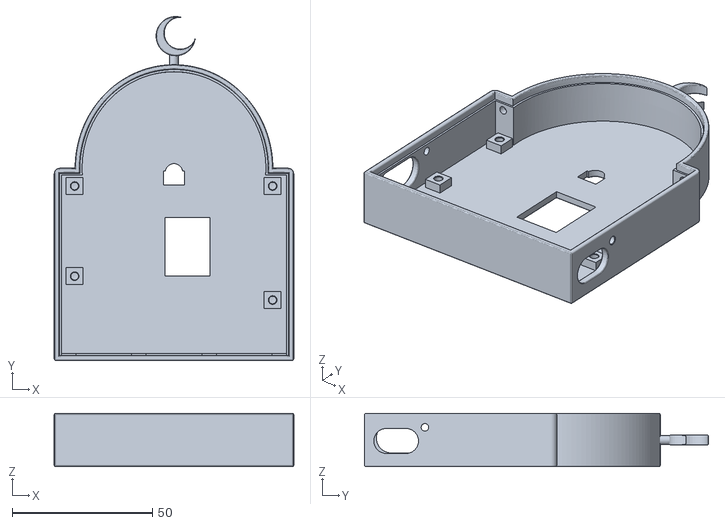
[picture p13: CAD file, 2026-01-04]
hardware/encolsure/Iteration13/bot13_RectSpeaker.stl
85.3 x 122.5 x 19.0

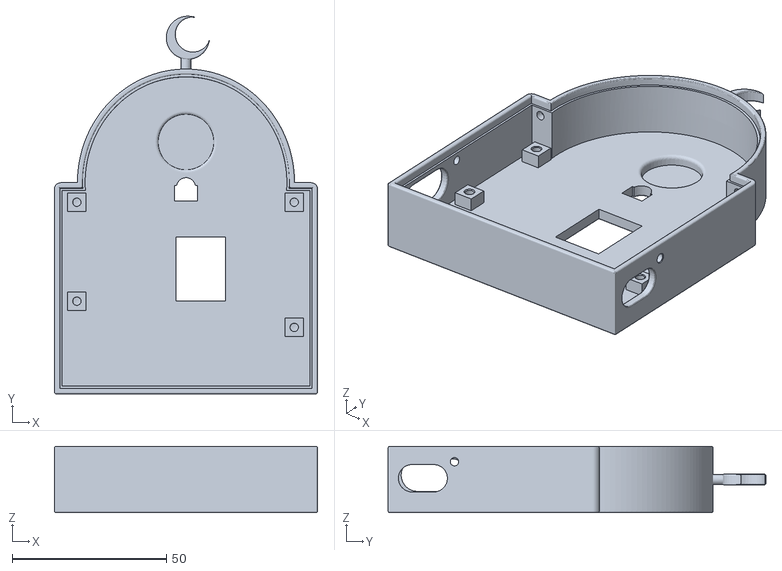
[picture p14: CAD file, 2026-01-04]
hardware/encolsure/Iteration13/bot13_RoundSpeaker.stl
85.3 x 122.5 x 21.5

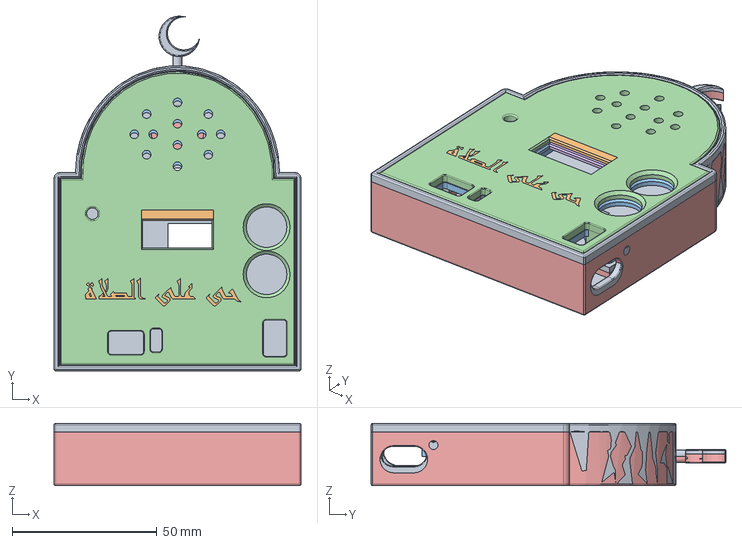
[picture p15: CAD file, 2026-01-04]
hardware/encolsure/Iteration13/cover13.step
85.3 x 122.5 x 21.5 mm

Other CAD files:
hardware/encolsure/Iteration13/top13_RectSpeaker_GDisplay.stl
hardware/encolsure/Iteration13/top13_RoundSpeaker_VDisplay.stl
hardware/encolsure/Iteration13/top13_RoundSpeaker_GDisplay.stl
hardware/encolsure/Iteration13/cover13.f3d

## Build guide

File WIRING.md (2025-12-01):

## Wiring Summary

This document summarizes the hardware connections implied by `athan.yaml` for the ESP8266 (`d1_mini` board). It lists every ESP pin as `D# (GPIO#)` where applicable, shows how power should be arranged (ESP from a 3.3V regulator; input power provided directly to modules), recommends decoupling caps, and includes a simple wiring table.

### Assumptions and notes
- **Board:** Wemos/D1 Mini (ESP8266) as configured by `esp8266.board: d1_mini`.
- **Power:** Input power (Vin) is the raw supply from your adapter (commonly 5V or higher). Per your request, Vin goes directly to modules that need it (DFPlayer, relay coils, etc.). The ESP8266 must be powered from a stable 3.3V regulator (do NOT feed Vin directly to the ESP 3.3V pin unless a regulated 3.3V supply is used).
- **Ground:** All grounds (ESP, DFPlayer, OLED module, relay, power supply) must be common.
- **Capacitors:** Add decoupling capacitors around the regulator and the modules:
  - Input (Vin) side: 100 µF electrolytic (or 47–220 µF) + 0.1 µF ceramic close to regulator input.
  - Regulator output (3.3V): 10 µF (or 22 µF) electrolytic + 0.1 µF ceramic close to ESP Vcc.
  - Near DFPlayer: at least 100 µF electrolytic (DFPlayer can draw spikes on playback).

### GPIO label map (Wemos D1 mini)
This shows the common D# ↔ GPIO# mapping for the `d1_mini` that is used in `athan.yaml`.

- `D0 (GPIO16)`
- `D1 (GPIO5)`
- `D2 (GPIO4)`
- `D3 (GPIO0)`
- `D4 (GPIO2)`
- `D5 (GPIO14)`
- `D6 (GPIO12)`
- `D7 (GPIO13)`
- `D8 (GPIO15)`
- `TX (GPIO1)` — serial TX0
- `RX (GPIO3)` — serial RX0

When this document lists a pin such as `D5 (GPIO14)`, it means the board pin labelled `D5` which is `GPIO14` on the ESP8266.

### Power rails (recommended wiring)

- `Vin` (input power from adapter): e.g., 5V (or 5–12V depending on your modules). Connect `Vin` to the 5V devices that require it (DFPlayer Vcc, relay Vcc if using a relay module), and to the input of the 3.3V regulator.
- `3.3V` (regulator output): connect to the ESP8266 `3V3` pin and to 3.3V devices like an SSD1306 module when it is a 3.3V version.
- `GND`: common ground to all modules and the regulator.

Recommended quick parts list for power stability:
- Voltage regulator: e.g., an AMS1117-3.3, or a switching buck regulator capable of supplying ~500–1000 mA for ESP + DFPlayer and other loads.
- Caps: Input 100 µF + 0.1 µF, Output 10 µF + 0.1 µF. DFPlayer: 100 µF at its Vcc.

### Connections table (signals extracted from `athan.yaml`)

| Component | ESP pin | ESP pin (GPIO#) | Wire To (module pin) | Notes |
|---|---:|---:|---|---|
| I2C SDA (SSD1306 SDA) | `D2` | `GPIO4` | `SSD1306 SDA` | I2C data line (pull-ups on module or board). SSD1306 `Vcc` should be 3.3V. |
| I2C SCL (SSD1306 SCL) | `D1` | `GPIO5` | `SSD1306 SCL` | I2C clock line. Address used in config: `0x3D`. |
| SSD1306 RESET | `D0` | `GPIO16` | `SSD1306 RST` | Reset pin wired to `D0 (GPIO16)` as `reset_pin: D0` in YAML. |
| DFPlayer RX (module RX) <= MCU TX | `TX` | `GPIO1` | `DFPlayer RX` | UART TX from MCU connects to DFPlayer RX. In `athan.yaml`: `uart.tx_pin: GPIO1` (i.e. TX). |
| DFPlayer TX (module TX) => MCU RX | `RX` | `GPIO3` | `DFPlayer TX` | UART RX from module to MCU RX. In `athan.yaml`: `uart.rx_pin: GPIO3`. |
| ui_next (button) | `D5` | `GPIO14` | `Button` -> `GND` (button to ground) | Configured as `INPUT_PULLUP` and `inverted: true` in YAML. Connect one side of the button to `D5`, the other to GND. |
| ui_select (button) | `D6` | `GPIO12` | `Button` -> `GND` | Also `INPUT_PULLUP` + `inverted: true`. |
| Built-in LED (output) | `D4` | `GPIO2` | `LED` (via `led_output`) | `output:` uses `GPIO2` and `inverted: true` in `light` entry; that maps to the built-in LED on many boards. |
| External relay control | `D7` | `GPIO13` | `Relay module IN` | Relay Vcc -> Vin (5V) (module dependent), GND common. If using a bare relay coil, use a transistor/driver and diode; if module, ensure its Vcc matches Vin. |
| DFPlayer / Audio control | (no extra pin) | | `dfplayer` component uses UART pins above | DFPlayer playback files are triggered from the firmware. DFPlayer requires 5V Vcc typically — feed from Vin (not 3.3V). |

### Power wiring table

| Rail | Source | Destinations | Notes |
|---|---|---|---|
| `Vin` (raw input, often 5V) | Adapter / battery | `DFPlayer Vcc`, `Relay Vcc` (module), other 5V modules | Provide common ground. |
| `3.3V` (regulated) | 3.3V regulator output | `ESP8266 3V3`, `SSD1306 Vcc` (if 3.3V version) | Use recommended caps near regulator and ESP. |

### Button wiring detail

- Both `ui_next` and `ui_select` are configured with `mode: INPUT_PULLUP` and `inverted: true` in `athan.yaml`. That means:
  - Wire one side of each button to the ESP pin (`D5` or `D6`).
  - Wire the other side to `GND`.
  - The firmware uses the internal pull-up; pressing the button pulls the pin low.

### DFPlayer notes
- DFPlayer Mini typically requires 5V on `Vcc` and draws current during playback. Provide a solid 5V supply (Vin) and a 100 µF electrolytic near the DFPlayer power pins.
- UART wiring: MCU `TX` (GPIO1) -> DFPlayer `RX`; MCU `RX` (GPIO3) <- DFPlayer `TX`.

### Relay notes
- If using a relay module with an onboard driver, you can power its Vcc from `Vin` and drive its input from `D7 (GPIO13)`. Ensure the relay module's input logic matches the ESP logic or use a transistor level-shifter/driver. For a bare relay coil, use a transistor + diode + external supply sized for the coil.

### Recommended decoupling placements (quick)
- Place 100 µF electrolytic at Vin near the board entry point.
- Place 100 µF electrolytic close to DFPlayer Vcc and a 0.1 µF ceramic nearby.
- Place 10 µF + 0.1 µF at the regulator output (3.3V) close to the regulator.
- Place a 0.1 µF ceramic right across the ESP 3V3 and GND pins.

### Final checklist before powering up
- Verify common ground between Vin, regulator ground, DFPlayer, relay, and ESP.
- Verify the regulator is a stable 3.3V supply capable of the total expected current (ESP8266 + any WiFi peaks + peripherals).
- Confirm DFPlayer & relay Vcc ratings and connect them to Vin (not to the 3.3V regulator) if they require 5V.
- Add caps as recommended.

This file is derived from the current `athan.yaml` pin assignments. If you change pins in the YAML, please remember to update this wiring summary to match.

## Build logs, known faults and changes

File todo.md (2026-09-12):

# ESP Athan TODO

## Next Versionxw

### DFPlayer: hardware changes for the next PCB

**IMPORTANT, do first: wire the DFPlayer BUSY pin to a spare ESP GPIO.**
- BUSY is low while the module plays and high when idle. Today the firmware only knows what it *asked* the module to do; with BUSY it knows what the module is *doing*. That turns every guess into a check: "asked to play but BUSY says idle" (stuck / ignored command → resend or power-cycle), "playing when nothing was requested" (runaway → stop), and it is what a proper playback watchdog needs.
- GPIO choice: GPIO0 is the practical candidate (BUSY idles high, which is the normal-boot level for GPIO0; it is also the programming pin, so it must be easy to isolate on the header). GPIO15 cannot be used (BUSY high at boot would select the wrong boot mode). GPIO2 drives the LED, GPIO16 the OLED reset.

**Optional: DFPlayer power through an N-channel MOSFET (or NPN) on a spare GPIO.**
- Lets the firmware do the only thing that reliably recovers a locked clone (LED stuck on, no audio; the serial reset 0x0C does not): cut VCC, wait ~500 ms, restore, wait ~3 s, restore the volume.
- Bonus: keep the module unpowered for the first ~3 s after the ESP boots so it never sees the ESP8266 boot-ROM log on GPIO1 (its RX line), the classic cause of clones playing on their own after a reset. The firmware already sends stops after boot as a workaround.
- Firmware side once it exists: a watchdog on expected playback duration (short click vs athan) that power-cycles the module when it is "playing" far longer than it should, or, with BUSY wired, whenever BUSY contradicts the request.

**Optional: DFPlayer RX on GPIO15 instead of GPIO1.**
- ESP8266 UART0 can be swapped to TX=GPIO15 / RX=GPIO13 in `uart:`; the boot ROM only prints on GPIO1, so the module would never hear it. GPIO13 is the relay today and would have to move.

## Fallback only: single settings block in flash (do NOT do this unless the preference store runs out)

The ESP8266 flash preference store is 128 words. Each persisted object costs its size rounded up to
4-byte words plus one checksum word, so a lone bool or int costs 2 words whatever its type; only arrays
and strings get cheaper with smaller types. As of 2026-09-12 the firmware uses 85 words (globals 48,
relay switch 2, Wi-Fi credentials 26, API key 9). The store is positional (slot = setup order), so any
added/removed/resized persisted object moves the slots after it and resets them once (Wi-Fi and mosque
included). Never add a persisted global casually.

If more settings are ever needed and the words run out, switch to ONE persisted global
`settings` of type `uint8_t[128]` (33 words for everything the app owns, ~70 words total with relay,
Wi-Fi and API) and keep every existing global as it is but with `restore_value: false`:

- byte 0: layout version (lets a later change migrate instead of discarding)
- byte 1: flags: locked, 12h clock, Q, Fajr/Dhuhr/Asr/Maghrib/Isha on/off
- bytes 2-9: volume, Fajr volume, athan choice, Fajr athan choice, tick choice, window start, window end, location index
- bytes 10-13: cached schedule day and year
- bytes 14-27: seven prayer times as 16-bit minutes-of-day
- bytes 28-75: timezone string (POSIX strings are 22-35 chars)
- bytes 76-127: spare (future settings go here, no slot ever moves again)

Implementation: one `unpack` lambda in `on_boot` (block -> globals) and one `pack` step in the 1 s
`sync_web_state` interval (globals -> block, copied only if a byte differs; ESPHome then writes the
flash). No other code in the file changes.

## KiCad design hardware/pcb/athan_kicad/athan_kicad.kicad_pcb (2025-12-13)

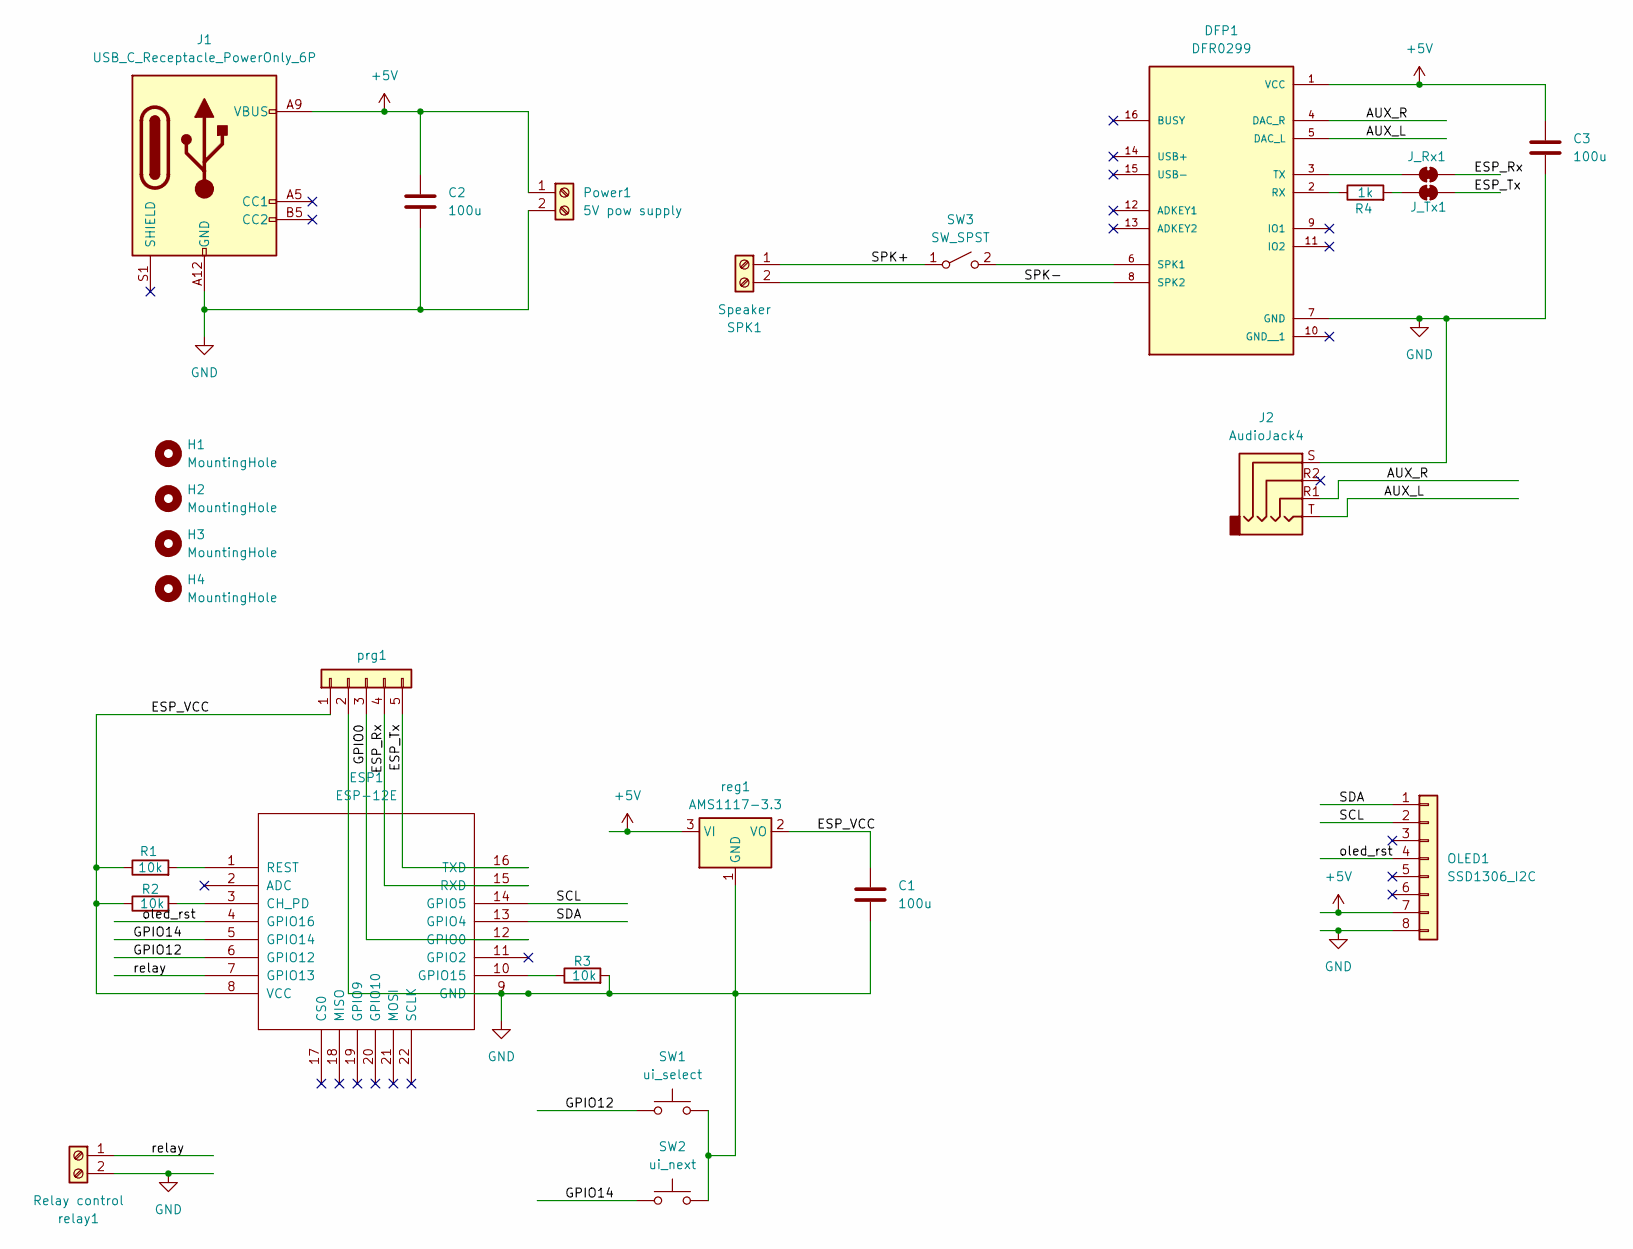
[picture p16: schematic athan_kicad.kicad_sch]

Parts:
C1, C2, C3: 100u; CP_Radial_D10.0mm_P5.00mm_P7.50mm
DFP1: DFR0299; MODULE_DFR0299
ESP1: ESP-12E; ESP-12E_SMD
H1, H2, H3, H4: MountingHole; MountingHole_3.2mm_M3
J1: USB_C_Receptacle_PowerOnly_6P; USB_C_Receptacle_GCT_USB4125-xx-x_6P_TopMnt_Horizontal
J2: AudioJack4; Jack_3.5mm_PJ320A_Horizontal
J_Rx1: SolderJumper_2_Bridged; SolderJumper-2_P1.3mm_Bridged2Bar_RoundedPad1.0x1.5mm
J_Tx1: SolderJumper_2_Bridged; SolderJumper-2_P1.3mm_Bridged2Bar_RoundedPad1.0x1.5mm
OLED1: SSD1306_I2C; Adafruit_SSD1306_multi
Power1: 5V pow supply; TerminalBlock_MaiXu_MX126-5.0-02P_1x02_P5.00mm
R1, R2, R3: 10k; R_Axial_DIN0207_L6.3mm_D2.5mm_P7.62mm_Horizontal
R4: 1k; R_Axial_DIN0207_L6.3mm_D2.5mm_P7.62mm_Horizontal
SPK1: Speaker; TerminalBlock_MaiXu_MX126-5.0-02P_1x02_P5.00mm
SW1: ui_select; SW_SPST_Omron_B3F-40xx
SW2: ui_next; SW_SPST_Omron_B3F-40xx
SW3: SW_SPST; SW_Slide-03_Wuerth-WS-SLTV_10x2.5x6.4_P2.54mm
prg1: Conn_01x05; PinHeader_1x05_P2.54mm_Vertical
reg1: AMS1117-3.3; SOT-223-3_TabPin2
relay1: Relay control; TerminalBlock_MaiXu_MX126-5.0-02P_1x02_P5.00mm

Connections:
+5V: C2.1, C3.1, DFP1.1 (VCC), J1.A9 (VBUS), J1.B9 (VBUS), OLED1.7, Power1.1, reg1.3 (VI)
/AUX_L: DFP1.5 (DAC_L), J2.T
/AUX_R: DFP1.4 (DAC_R), J2.R1
/ESP_Rx: ESP1.15 (RXD), J_Rx1.2 (B), prg1.4
/ESP_Tx: ESP1.16 (TXD), J_Tx1.2 (B), prg1.5
/ESP_VCC: C1.1, ESP1.8 (VCC), R1.1, R2.1, prg1.1, reg1.2 (VO)
/GPIO0: ESP1.12 (GPIO0), prg1.3
/GPIO12: ESP1.6 (GPIO12), SW1.1
/GPIO14: ESP1.5 (GPIO14), SW2.1
/SCL: ESP1.14 (GPIO5), OLED1.2
/SDA: ESP1.13 (GPIO4), OLED1.1
/SPK+: SPK1.1, SW3.1 (A)
/SPK-: DFP1.8 (SPK2), SPK1.2
/oled_rst: ESP1.4 (GPIO16), OLED1.4
/relay: ESP1.7 (GPIO13), relay1.1
GND: C1.2, C2.2, C3.2, DFP1.7 (GND), ESP1.9 (GND), J1.A12 (GND), J1.B12 (GND), J2.S, OLED1.8, Power1.2, R3.2, SW1.2, SW2.2, prg1.2, reg1.1 (GND), relay1.2
unnamed: DFP1.2 (RX), R4.1
unnamed: DFP1.6 (SPK1), SW3.2 (B)
unnamed: DFP1.3 (TX), J_Rx1.1 (A)
unnamed: ESP1.3 (CH_PD), R2.2
unnamed: ESP1.10 (GPIO15), R3.1
unnamed: ESP1.1 (REST), R1.2
unnamed: J_Tx1.1 (A), R4.2

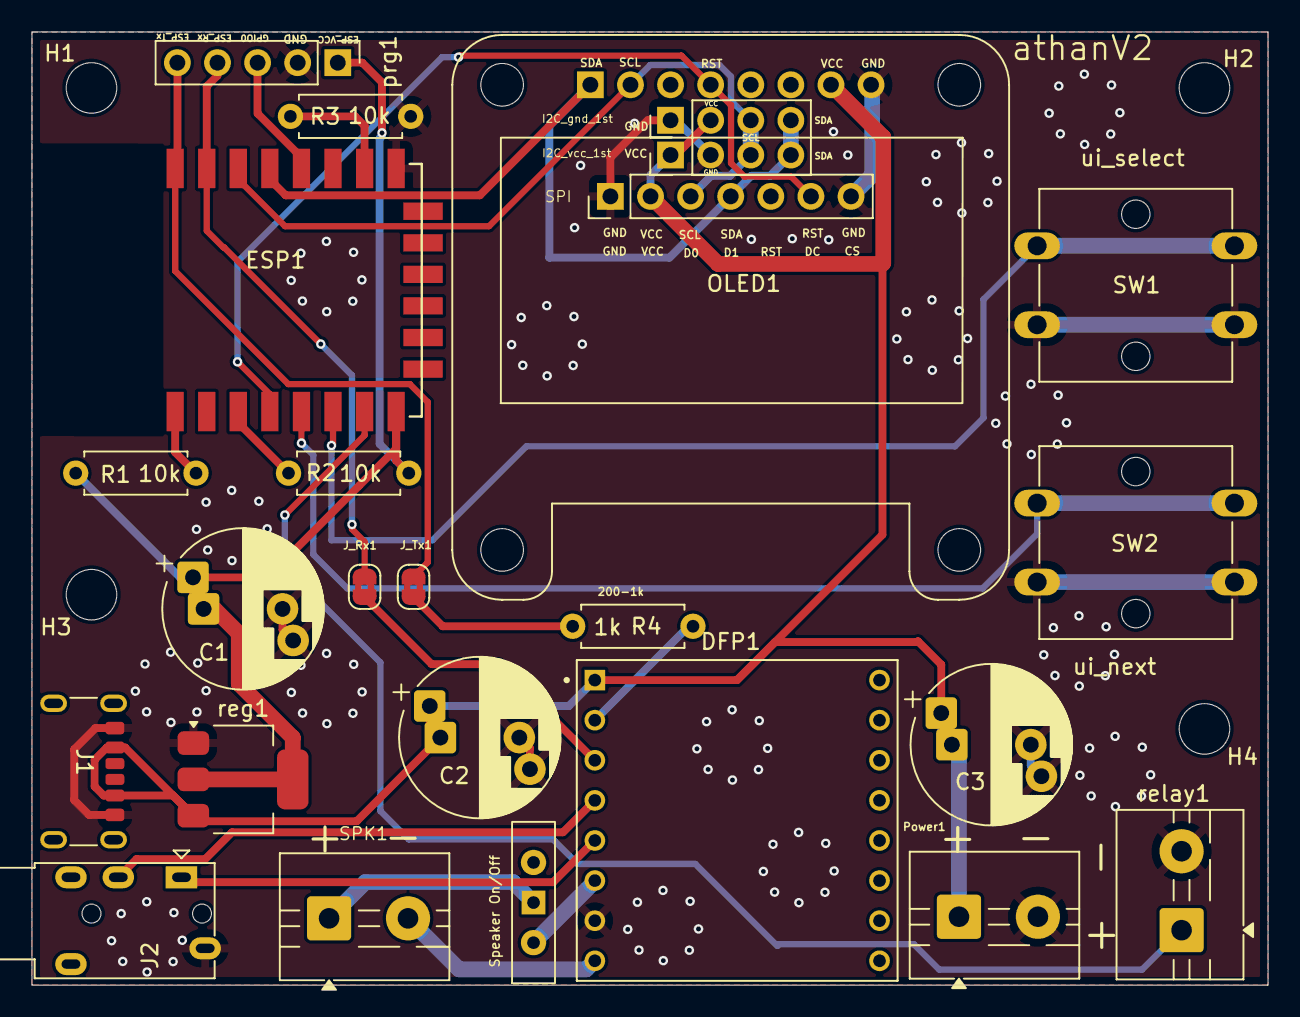
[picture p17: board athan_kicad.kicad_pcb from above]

Board: 2 copper layers, 78.3 x 60.4 mm, 26 parts (0 on the bottom side), 23 nets.

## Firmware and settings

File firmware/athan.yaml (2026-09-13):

substitutions:
  current_version: "6"

  # ---------------------------------------------------------------
  # DFPlayer / SD-card file layout. The DFPlayer numbers files by the
  # order they were copied to the card (see README section 2.6 and
  # SDCard_files/cpy_script.sh). Change these together with the card.
  # ---------------------------------------------------------------
  athan_file_first: "1"    # A1..A10 -> files 1..10  regular athans   (choice k -> file k)
  htick_file_first: "11"   # B1..B10 -> files 11..20 hourly ticks     (tick t   -> file 10+t)
  tone_volume_file: "22"   # C2      -> volume feedback tone
  tone_click_file: "23"    # C3      -> menu click
  quyam_file_first: "25"   # D1..D10 -> files 25..34 Quyam audio (random pick)
  quyam_file_last: "34"
  fajr_file_first: "35"    # F1..F10 -> files 35..44 Fajr-wording athans (choice k -> file 34+k)
  # Z_fallback_1..4 -> files 45..48. Never referenced by number; must be copied LAST.

  # OLED orientation / contrast (the display: block reads these; change them here).
  oled_flip_x: "true"      # ESPHome default true; set both flips to false to rotate the screen 180 degrees
  oled_flip_y: "true"
  oled_contrast: "1.0"     # 0.0 .. 1.0
  oled_reset_pin: "16"     # GPIO16 to the module's RES pin if it has one (4-pin modules do not); pulsed by ESPHome at every setup

  # ---------------------------------------------------------------
  # NOTE for people just changing the OLED / SSD1306 display
  # ---------------------------------------------------------------
  # The display configuration are further down in this file under
  # the `display:` section with `platform: ssd1306_i2c`.
  #
  # Common things you may want to tweak:
  #   - I2C address: the line `address: ` can be changed between
  #     `0x3C` and `0x3D` depending on your model.
  #   - Orientation: set the `oled_flip_x` / `oled_flip_y`
  #     substitutions just below if your screen is mounted upside
  #     down or mirrored (to rotate 180° you usually flip both).
  #
  # You normally do NOT need to touch other parts of this file if
  # you only want to adapt the SSD1306 display.

esphome:
  name: athan
  friendly_name: athan
  on_boot:
    then:
      - lambda: |-
          ESP_LOGI("tz", "Applying saved timezone on boot: '%s'", id(selected_location_tz).c_str());
          id(sntp_time).set_timezone(id(selected_location_tz).c_str());
      - if:
          condition:
            and:
              - binary_sensor.is_on: ui_next
              - binary_sensor.is_on: ui_select
          then:
            - logger.log: "on resetting wifi"
            - wait_until:
                timeout: 5min
                condition:
                  wifi.connected:
            - lambda: |-
                wifi::global_wifi_component->clear_sta();
                wifi::global_wifi_component->save_wifi_sta("doesntexist", "passwordfornonetwork");
            - output.turn_off: led_output
            - delay: 1s
            - output.turn_on: led_output
            - delay: .5s
            - output.turn_off: led_output
            - delay: 1s
            - output.turn_on: led_output
            - delay: .5s
            - output.turn_off: led_output
            - logger.log: "resetting"
            - switch.turn_on: _restart
      # Hardware unlock for the button lock: power up holding exactly ONE of the two buttons.
      # (Both held is the Wi-Fi reset above, unchanged.)
      - if:
          condition:
            lambda: 'return id(buttons_locked) && (id(ui_next).state != id(ui_select).state);'
          then:
            - lambda: |-
                id(buttons_locked) = false;
                ESP_LOGI("ui", "Buttons unlocked (one button held at power-up)");
            - output.turn_on: led_output
            - delay: 150ms
            - output.turn_off: led_output
            - delay: 150ms
            - output.turn_on: led_output
            - delay: 150ms
            - output.turn_off: led_output
            - delay: 150ms
            - output.turn_on: led_output
            - delay: 150ms
            - output.turn_off: led_output
      - lambda: |-
          // First boot after the update: Fajr volume starts equal to the main volume.
          if (id(fajr_volume_level) < 0) {
            id(fajr_volume_level) = id(volume_level);
            ESP_LOGI("audio", "Fajr volume initialised to %d%% (from main volume)", id(fajr_volume_level));
          }
          if (id(fajr_athan_choice) < 1 || id(fajr_athan_choice) > 10) {
            id(fajr_athan_choice) = id(athan_file_index) - (${athan_file_first} - 1);
            ESP_LOGI("audio", "Fajr athan choice initialised to %d (same as the regular athan)", id(fajr_athan_choice));
          }
      # # # for testing with RPI:
      # - output.turn_off: gpio0_output
      # - delay: 200ms
      # - output.turn_on: gpio0_output 
      - delay: 3s                # cheap DFPlayer clones need 2-3 s after power before they listen
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

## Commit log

2025-12-02 fixing hour tick menu
    [athan.yaml]
2025-12-02 flip screen vertically option commented, also making athan select menu similar to hourly tick
    [athan.yaml]
2025-12-02 default flipped so making false optinal
    [athan.yaml]
2025-12-02 flip would require both x and y or neither to keepp orientation
    [athan.yaml]
2025-12-05 bug fix athan wasnt playing when matching a Htick
    [athan.yaml]
2025-12-09 dummy wifi reset network to force into captive portal - bug fix
    [athan.yaml]
2025-12-10 suggesting power strip and 'Q:' notice
2025-12-11 PCB schematic updated with fixes of the previous version. The Layout is not done yet. Check the previous commit for a previous version layout
    [athanV1.kicad_pcb, athan_kicad.csv, athan_kicad.kicad_pcb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]
2025-12-11 explain the uart conflict in README
2025-12-12 PCB V2 in progress
    [athan_kicad.kicad_pcb, athan_kicad.kicad_sch]
2025-12-13 enhancing schematic: adding 1k resistor before dfplayer Rx for eleminating potential buzzing. changing AUX jack footprint from PJ320E to PJ320A which is a mirrored image (more available on stores). P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
    [BOM_from_schematic.csv, BOM_with_pictures.xlsx, athan_kicad.kicad_pcb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]
2025-12-13 athanV2 PCB finished (hopefully)
    [athan_kicad.kicad_pcb]
2025-12-13 fixing a couple fo labels
    [athan_kicad.kicad_pcb]
2025-12-13 follow up
    [athan_kicad.kicad_pcb]
2025-12-19 firmware V2: using rawcdn instead of raw urls for production avoiding redirects with unlimited traffic. updated the binaries and build as well
    [athan.yaml]
2025-12-30 readme adding enclosure and acknowledgement
2026-01-03 3D of enclosure finally Added!!
    [bot11_RectSpeaker.stl, bot11_RoundSpeaker.stl, cover11.f3d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]
2026-01-03 enclosure 3D few changes for better fit
    [bot11_RectSpeaker.stl, bot11_RoundSpeaker.stl, bot12_RectSpeaker.stl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]
2026-01-04 Enclosure iteration 13, fixing the height of the roundspeaker enclosure, adding chamfers for more friendly 3D printing, and minor other fixes
    [bot12_RectSpeaker.stl, bot12_RoundSpeaker.stl, bot13_RectSpeaker.stl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]
2026-02-22 next button toggles output when not in menu and no athan playing
2026-02-23 relay control wihtout homeasssistant
2026-03-19 bug fix: adding dfplayer debounce and fixing back to back comms, hopefully this fixes the getting stuck bug.
    [athan.yaml]
2026-09-10 Firmware V6: per-prayer athan on/off, Fajr recordings, full web control
    Adds three user-facing features to the athan clock and fixes the boot
    crash found while testing them. All logic is still in firmware/athan.yaml.
    Per-prayer athan on/off
    - New persisted flags (athan_enabled[7], all ON by default) for Fajr,
    Dhuhr, Asr, Maghrib and Isha. A prayer that is OFF keeps its place in
    the schedule and countdown but plays no athan and does not light the LED.
    - New "Athan On/Off" main-menu item with a submenu (Next cycles the
    prayers and Done, Select toggles). On the normal screen the last two
    letters of a muted next prayer are struck through.
    Fajr-wording recordings
    - Every athan choice k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
    [athan.yaml]
2026-09-11 V6 (readjust): button lock, Fajr volume, tick window, 12-hour clock, headless display
    Firmware (firmware/athan.yaml):
    - Button lock: "Lock Buttons" menu item and web switch; locked buttons only
    silence audio. Unlock from the web page or by powering up holding one
    button (both buttons held is still the Wi-Fi reset). Padlock drawn on the
    screen while locked. Persisted.
    - Fajr volume: separate level for the Fajr athan and the Q- audio, with
    its own submenu and web slider; main volume restored afterwards. Starts
    equal to the main volume on first boot after the update.
    - Hourly-tick window: start/end hour [start, end), midnight wrap allowed,
    equal = all day (default, so nothing change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
    [athan.yaml]
2026-09-12 Cut down the flash usage by 35% without affecting performance, just choosing the right way to save data and right format.
